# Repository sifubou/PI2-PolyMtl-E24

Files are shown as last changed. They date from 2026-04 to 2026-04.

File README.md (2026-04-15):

# Le Dalmachien 🐕‍🦺

Prototype de chien robot autonome conçu dans le cadre du cours **MEC2105 · Projet Intégrateur II** (Polytechnique Montréal, Hiver 2026).

**Équipe 24 · Groupe 02**
Adam Bouaddi · Rose Mélançon · Liliane Leclerc-Ko · Miguel Azoury · Ryan Kangue Essomé Simeu · William Lalonde

## Mission
Parcourir une piste de compétition, déposer un jouet poulet dans la zone cible, s'immobiliser dans deux cercles rouges successifs avec battement de queue et clignotement LED, puis exécuter une rotation complète dans le cercle BONUS.

## Matériel
- Microcontrôleur : Arduino Uno
- Moteurs : 2 × DC TT bleu, 110 tr/min (haut couple)
- Servomoteurs : 3 × MG90S (2 tête, 1 queue)
- Gyroscope : MPU6050 (asservissement des rotations)
- Alimentation : 2 × piles Li-ion 18650 (3500 mAh)
- LED : anneau NeoPixel 20 × WS2812

## Bibliothèques Arduino requises
- `Servo.h` (standard)
- `Adafruit_NeoPixel`
- `Wire.h` (standard, pour I²C du MPU6050)

## Brochage
| Fonction | Pin Arduino |
|---|---|
| Moteur IN1, IN2, IN3, IN4 | 2, 3, 4, 7 |
| Servo queue | 12 |
| Servo tête gauche / droite | 9 / 10 |
| LED NeoPixel | 6 |
| MPU6050 (I²C SDA/SCL) | A4 / A5 |

## Calibration
- `VITESSE_MS = 7000` ms/m (à calibrer sur la piste réelle)
- `DEG_PAR_SEC = 112` °/s (régulation gyroscopique)

## Fichiers
- `arduino/V3.ino` — programme du parcours complet (parcours obligatoire + BONUS)

## Licence
MIT

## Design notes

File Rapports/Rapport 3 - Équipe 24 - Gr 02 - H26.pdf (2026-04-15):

M E C 2 1 0 5 – P R O J E T I N T É G R A T E U R I I

Gr : 02

# RAPPORT 3

# Le Dalmachien

Projet intégrateur 2 : Robot chien

Présenté à

Vincent Di Pietro, ing.

Par l'équipe no 24

Rose Melançon • Adam Bouaddi • Liliane Leclerc-Ko

Miguel Azoury • Ryan Kangue Essome Simeu • William Lalonde

Hiver 2026 • Montréal

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
## TABLE DES MATIÈRES

### 01 Présentation de la solution

### 02 Essais du prototype

### 03 Analyse de la solution

### 04 Dessins techniques

### 05 Nomenclature

### 06 Conclusion

MEC2105 – Projet Intégrateur II – Équipe 24

A
A

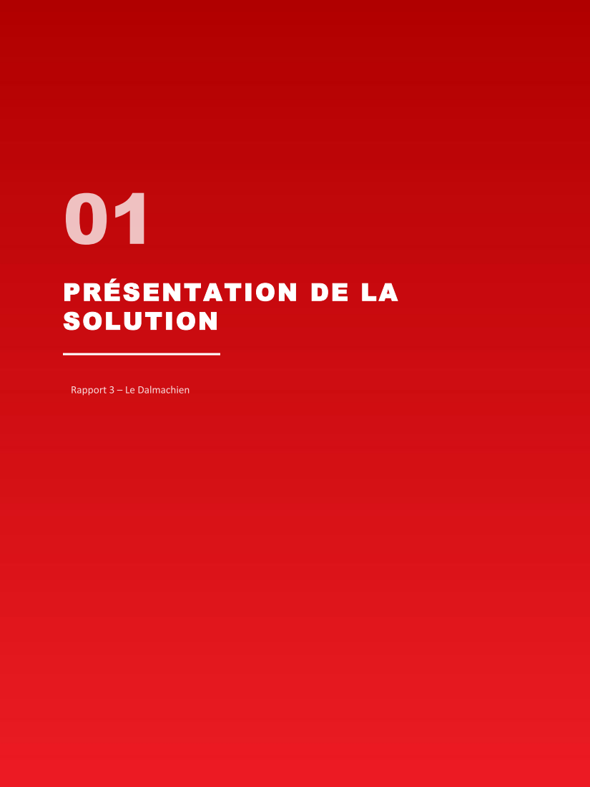
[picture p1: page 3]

PRÉSENTATION DE LA
SOLUTION

1

2

3

4

5

6

1 . P R É S E N T A T I O N

## Description de la solution

1.1 – Vue d'ensemble du Dalmachien

MEC2105 – Projet Intégrateur II – Équipe 24 | Section 1

Le Dalmachien (figure 1) est un robot chien qui répond parfaitement aux besoins des étudiants de l'école régionale du Vent-Nouveau. Il est composé de trois sous-systèmes : La queue, la tête et le châssis.

Figure 1 – Le Dalmachien

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
1 . P R É S E N T A T I O N

## Sous-système du chassis

1.1 – Description de la solution

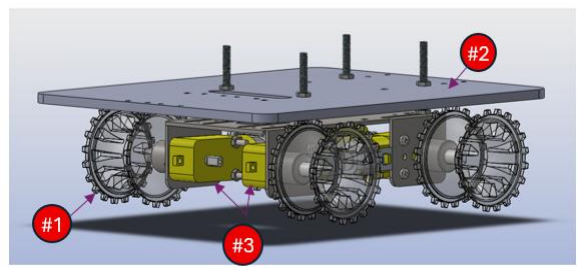
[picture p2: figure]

Figure 2 – Le sous-système du châssis

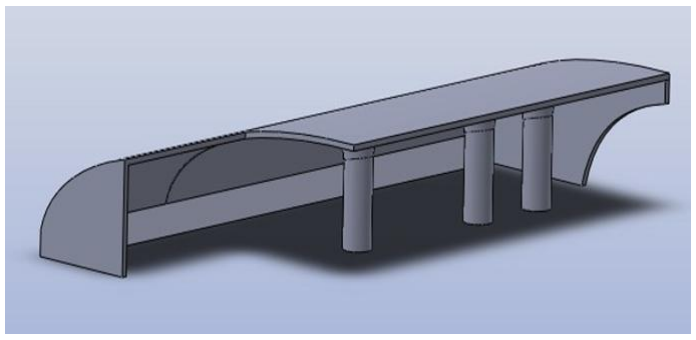
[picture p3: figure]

Figure 3 – Coquille du sous-système du châssis

### 1.1.1 Sous-système du châssis

Le premier sous-système est celui du châssis (voir figure 2). Sa pièce maîtresse est un châssis acheté, muni de chenilles (#1) et de deux moteurs DC (#3). Le sous-système comporte aussi un étage en acrylique (#2) qui permet de fixer toutes les pièces du système de contrôle : les servomoteurs, les moteurs, le pont H, les piles, le circuit électrique, etc. Il est aussi muni de la coquille en PLA (voir figure 3) qui permet de recouvrir les pièces techniques pour améliorer l'aspect esthétique du robot chien.

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
1 . P R É S E N T A T I O N

## Sous-systèmes tête et queue

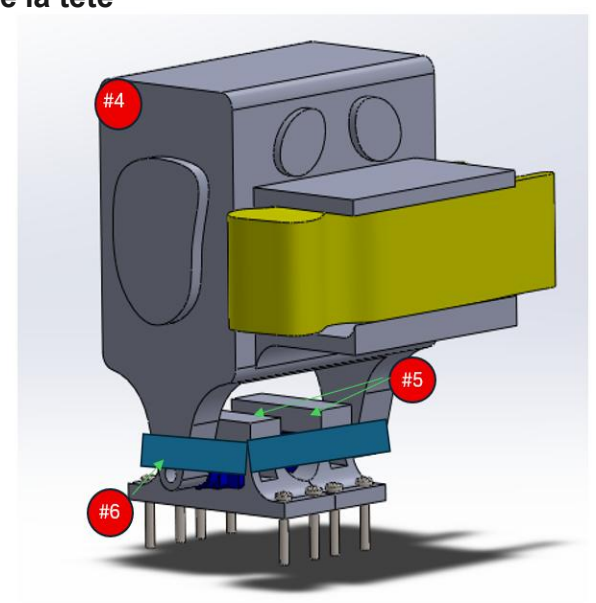
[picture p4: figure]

Figure 4 – La tête

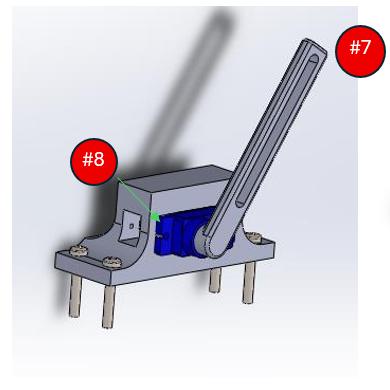
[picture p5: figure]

Figure 5 – La queue

Le deuxième sous-système est celui de la tête (voir figure 4). Il est composé de la tête en PLA (#4) qui sert à transporter le jouet poulet (illustré en jaune) et est recouvert d’une bande LED (#6) dans le bas du cou. La mâchoire est fixe et seulement le cou est contrôlé par deux servos moteurs (#5). La rotation permet de bien déposer le jouet poulet.

### 1.1.2 Sous-système de la tête

### 1.1.2 Sous-système de la queue

Le dernier sous-système est celui de la queue (voir figure 5). La composante principale est la queue imprimée en PLA (#7) directement fixée sur un servo moteur (#8). Elle est fixée sur l’étage du sous-système du châssis à l’arrière du robot.

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
1 . P R É S E N T A T I O N

## Axes d’améliorations

La solution initiale comportait une coquille en un morceau. Pour faciliter le montage et le démontage, le Dalmachien utilise maintenant 2 coquilles symétriques (figure 3) qui s'insèrent sur les tiges de l'étage (#2). La taille du chien a été réduite et la tête allégée.
De plus, la mâchoire est directement imprimée sur la tête du robot (figure 4), sans moteur, fonctionnelle uniquement par rotation du cou.

### 1.1.4 Amélioration du concept

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
1 . P R É S E N T A T I O N

## Fonctionnement de la solution

1.2 – Mécanismes principaux
Dans cette section, on décrit le fonctionnement des mécanismes principaux qui permettent au Dalmachien de remplir ses fonctions principales : battre de la queue, allumer un voyant lumineux, se déplacer, s'orienter et manipuler un jouet poulet (voir Annexe A).

### 1.2.1 Battre de la queue

Le mécanisme du sous-système de la queue (voir figure 5) est l’un des systèmes les plus simples du robot. Il fait appel à une queue imprimée en 3D, accouplée sur l’axe d’un servo-moteur à l’aide d’une vis. Grâce au microcontrôleur Arduino UNO, on vient commander le servo-moteur, pour moduler l’amplitude de battement et la vitesse des cycles de battement de la queue.

### 1.2.2 Allumer un voyant lumineux

Pour la fonction principale du robot-chien traitant du voyant clignotant, le Dalmachien utilise une bande LED (voir figure 4 #6) collée sur la partie inférieure de la tête du chien. Avec le microcontrôleur, on vient contrôler la couleur, l’intervalle de clignotement, ainsi que l’intensité lumineuse de la bande LED.

### 1.2.3 Se déplacer

Pour bouger, le Dalmachien utilise un système de roues-chenilles faisant partie du sous-système du châssis (voir figure 2), propulsé par deux roues motrices motorisées par deux moteurs DC. Les deux autres roues, indépendantes et libres sur leurs axes, permettent aux chenilles de maintenir leur forme et leur tension. Elles sont accouplées aux boîtiers de deux moteurs DC, dont nous avons enlevé le moteur et le réducteur de vitesse, pour que leurs arbres deviennent libres et sans résistance. Pour contrôler son mouvement, les deux moteurs sont branchés à un contrôleur à moteur en pont H L293D (voir figure 6 pour le branchement, encadré en vert), qui en conjonction avec le microcontrôleur Arduino, permet de moduler le sens de rotation et la puissance de sortie des deux moteurs. Pour avancer, on commande aux deux moteurs de tourner vers l’avant, ce qui ensuite transmet le mouvement aux chenilles, qui elles transmettent la force au sol pour venir déplacer le robot. Pour reculer, le robot applique la même séquence d’action, sauf pour un sens inverse de rotation des moteurs.

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
1 . P R É S E N T A T I O N

## Fonctionnement de la solution

1.2 – Mécanismes principaux

### 1.2.5 Déposer le jouet poulet

Afin de transporter le jouet poulet de façon fiable, le Dalmachien fait recours à une mâchoire inférieure et supérieure espacées d'une longueur précise, ainsi qu'à une nervure au bout de la mâchoire inférieure (voir figure 4), de façon à ce que le jouet soit sécure dans la bouche du chien lors du déplacement. Ensuite, pour déposer le jouet poulet, le Dalmachien penche sa tête d'environ 90 degrés vers l'avant jusqu'à ce que le poids du jouet suffise pour qu'il s'échappe de la bouche et tombe juste en dessous. Ce qui permet le mouvement de la tête du chien, ce sont deux servomoteurs ancrés à deux points de pivots à la base du cou (voir figure 4 #5). Ceux-ci sont aussi commandés par le microcontrôleur Arduino, qui vient moduler leurs angles de rotation.

Pour changer de direction, le robot fait tourner chacune de ses chaînes dans le sens opposé à l'autre, à la même vitesse de rotation. Le chien pivote ainsi sur son axe azimutal sur 360 degrés, lui permettant de s'orienter dans n'importe quelle direction. Il peut soit tourner vers la gauche ou vers la droite, dépendamment si la chenille de gauche ou celle de droite tourne vers l'avant. Pour effectuer tout ceci, le robot utilise les mêmes composantes que pour se déplacer vers l'avant ou l'arrière, soit le microcontrôleur Arduino, le contrôleur de moteur L293D et les 2 moteurs DC.

### 1.2.4 S'orienter

Figure 6 - Circuit électrique du Dalmachien

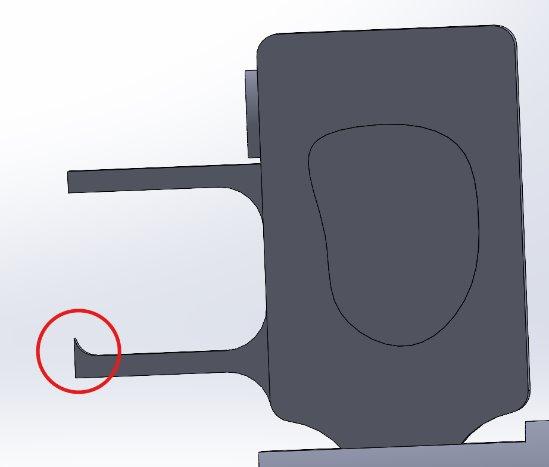
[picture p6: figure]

Figure 7 - Vue de côté de la tête

A
A

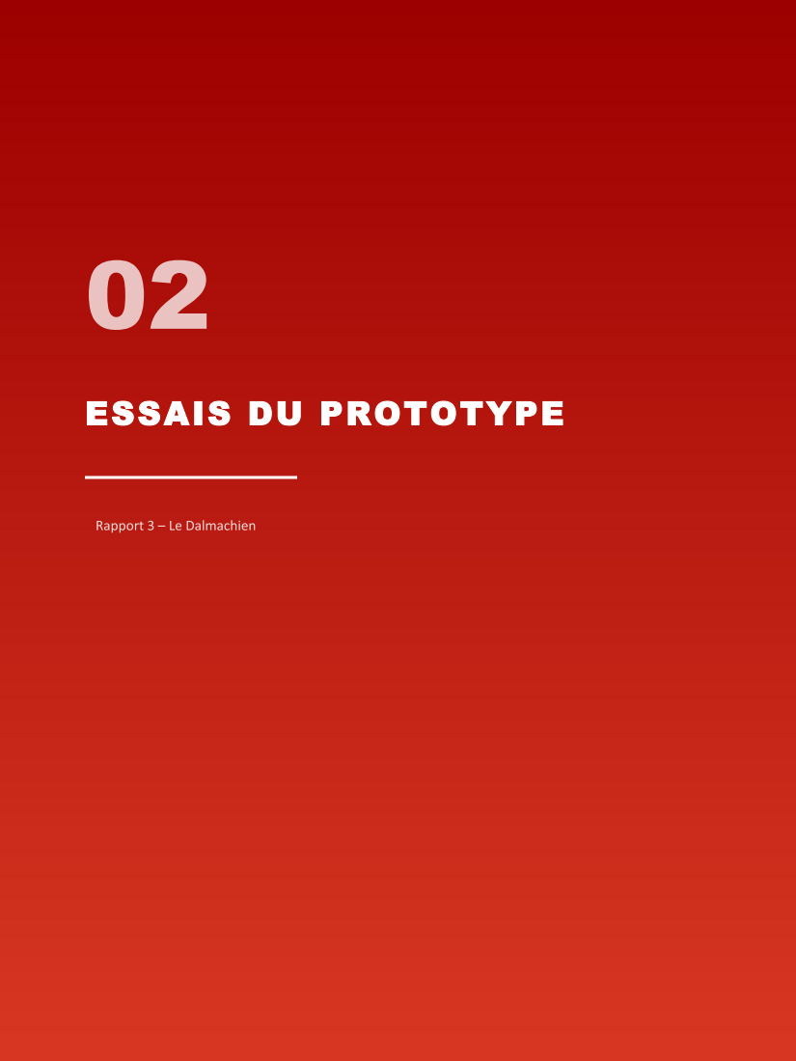
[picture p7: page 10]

ESSAIS DU PROTOTYPE

1

2

3

4

5

6

2 . E S S A I S

## Méthodologie générale

Protocole d'essai
L'ensemble des essais présentés dans ce rapport a été réalisé les 27 et 28 mars 2026. Chaque essai a été intégralement filmé afin de permettre une analyse rigoureuse a posteriori (voir Annexe I). Tous les essais sont numérotés, datés et rattachés aux fonctions principales (FP) du cahier des charges ainsi qu'aux paramètres de l'équation de performance.

Les vidéos ont été analysées à l'aide d'un logiciel de montage permettant un avancement image par image. La caméra utilisée opère à une fréquence de 60 Hz, ce qui correspond à une résolution temporelle d'environ 16,7 ms par image. La résolution spatiale de la caméra (inférieure à 4K) engendre également une incertitude estimée à ±5° sur les mesures angulaires.

En complément, une analyse de la piste audio a été effectuée afin de détecter les pics de bruit associés à l'activation des moteurs DC et des servomoteurs. Cette technique a permis d'améliorer la précision sur la détermination des instants de début et de fin de mouvement, en corroborant l'information visuelle.

SOURCES D'IMPRÉCISION IDENTIFIÉES

Taux de rafraîchissement limité à 60 Hz (±16,7 ms), résolution vidéo non 4K (±5° sur les angles), et maintien manuel du socle lors de certains essais (section 4).

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
2 . E S S A I S

## Essai n°1 : Locomotion et immobilisation

FP-1.0 et FP-1.1 – 27 mars 2026 – Paramètres D et temps
Cet essai porte sur les fonctions FP-1.0 (Se déplacer) et FP-1.1 (S'immobiliser). Ces fonctions sont directement liées aux paramètres D (distance parcourue) et temps (temps chronométré) de l'équation de performance (voir Annexe D).

Le prototype a été positionné sur une surface plane. Une distance de référence de 1 mètre a été marquée au sol. Le robot a été démarré par le bouton-poussoir et le chronométrage a été effectué par analyse vidéo image par image, corroboré par l'analyse audio de l'activation des moteurs. Le temps a été mesuré entre le premier déplacement détecté et l'immobilisation complète du prototype. Cinq (5) essais consécutifs ont été réalisés dans les mêmes conditions.

Essai | Temps (s) | Vitesse (m/s)
1 | 3,47 | 0,288
2 | 3,29 | 0,304
3 | 3,28 | 0,305
4 | 3,41 | 0,293
5 | 3,36 | 0,298
Moyenne | 3,36 | 0,298

Tableau 1 – Résultats des essais de locomotion (distance : 1 m)

L'écart-type calculé sur le temps est de 0,080 s. Le meilleur temps enregistré est de 3,28 s (essai n°3).

A NA L Y S E

La répétabilité des mesures est satisfaisante, avec un écart-type de 0,080 s sur cinq essais. La vitesse moyenne de 0,298 m/s permet de parcourir la distance maximale du parcours (Dmax = 178 cm) en environ 6 secondes, ce qui est largement inférieur à la limite de 120 secondes imposée. Le prototype s'immobilise de manière complète et sans rebond à chaque essai, validant ainsi la fonction FP-
1.1. Le système de propulsion par chenilles offre une traction stable et rectiligne sur la surface de la piste.

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
2 . E S S A I S

## Essai n°2 : Battement de queue

FP-5.0, FP-5.1, FP-5.2 – 27 mars 2026 – Param. S2, P3 = 100 pts

Un total de 36 mesures a été réalisé. Quatre angles cibles ont été programmés dans le servomoteur MG90S (90°, 120°, 150° et 180°) pour trois durées de cycle visées (1 s, 1,5 s et 2 s), chaque combinaison étant répétée trois fois. L'angle de battement a été mesuré par analyse vidéo image par image. La durée du cycle a été déterminée par combinaison de l'analyse vidéo et de l'analyse de la bande son, en repérant le pic acoustique correspondant à l'activation du servomoteur (voir Annexe E).

Angle | Durée | t1 (s) | t2 (s) | t3 (s) | Obs. moy. | Précision
90° | 1 s | 1,05 | 1,05 | 1,01 | 82° | 91,1 %
90° | 1,5 s | 1,53 | 1,53 | 1,53 | 85° | 94,4 %
90° | 2 s | 2,03 | 2,06 | 2,06 | 85° | 94,4 %
120° | 1 s | 1,01 | 1,11 | 1,08 | 105° | 87,5 %
120° | 1,5 s | 1,63 | 1,56 | 1,56 | 110° | 91,7 %
120° | 2 s | 2,05 | 2,08 | 2,10 | 110° | 91,7 %
150° | 1 s | 1,06 | 1,10 | 1,06 | 135° | 90,0 %
150° | 1,5 s | 1,65 | 1,63 | 1,56 | 140° | 93,3 %
150° | 2 s | 2,05 | 2,00 | 2,11 | 140° | 93,3 %
180° | 1 s | 0,96 | 0,96 | 0,96 | 158° | 87,8 %
180° | 1,5 s | 1,65 | 1,65 | 1,60 | 170° | 94,4 %
180° | 2 s | 2,00 | 2,00 | 2,00 | 170° | 94,4 %

Tableau 2 – Résultats des 36 mesures de battement de queue

A NA L Y S E
Les résultats montrent que le servomoteur MG90S produit un battement de queue reproductible pour l'ensemble des configurations testées. On observe un écart systématique d'environ 10° entre la consigne et l'angle observé pour la consigne de 90°, attribuable aux limites mécaniques du montage (jeu dans l'axe, inertie de la pièce de queue). Cet écart est problématique car il est impératif de dépasser les 90° par rapport à la verticale lors de la compétition. La précision angulaire s'améliore avec l'augmentation de l'angle cible, atteignant 93,3 % pour 150° et 94,4 % pour 180°.

Pour la compétition, la configuration retenue sera un angle cible de 150° ou 180° avec une durée de cycle de 1,5 seconde. À 150°/1,5 s, l'angle observé moyen est de 140° ; à 180°/1,5 s, il est de 170°. Les résultats de ces deux configurations sont proches et compte tenu de l'imprécision des mesures (±5°), ils peuvent être considérés comme similaires. Les deux dépassent largement le minimum requis de 90° et offrent une marge de sécurité confortable. La durée de cycle mesurée (environ 1,6 s en moyenne) satisfait le minimum de 1 seconde exigé. Les exigences des spécifications FP-5.0, FP-5.1 et FP-5.2 sont validées.

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
2 . E S S A I S

## Essai n°3 : Inclinaison de la tête

FP-4.0 et FP-4.3 – 28 mars 2026 – Param. O

Cet essai porte sur les fonctions FP-4.0 (Manipuler la charge utile) et FP-4.3 (Déposer un objet dans une zone prédéterminée). L'ouverture de la gueule à 90° (position horizontale) permet la libération du jouet poulet par gravité. Ce mécanisme influence directement le paramètre O de l'équation de performance (voir Annexe F).

La tête du chien robot, fabriquée par impression 3D, est actionnée par deux servomoteurs MG90S. Deux angles cibles ont été testés : 70° (position intermédiaire) et 90° (position horizontale nécessaire au dépôt). Cinq tests ont été réalisés pour chaque angle cible, soit un total de 10 mesures. L'angle a été mesuré par analyse vidéo image par image.

Il est important de noter deux limitations de cet essai. Premièrement, le socle du prototype était tenu manuellement durant les tests, ce qui introduit une source d'imprécision. Deuxièmement, un jouet de test a été utilisé en remplacement du jouet poulet officiel fourni lors de la compétition. La géométrie et la masse de ce jouet de test diffèrent légèrement du modèle réel.

Test | Obs. 70° | Obs. 90°
Test 1 | 70° | 80°
Test 2 | 70° | 85°
Test 3 | 70° | 88°
Test 4 | 70° | 90°
Test 5 | 70° | 90°
Moyenne | 70,0° | 86,6°

Tableau 3 – Résultats des essais d'inclinaison de la tête

A N A L Y S E

L'angle de 70° est atteint avec une précision de 100 % sur les cinq essais, ce qui confirme la fiabilité du mécanisme à cette position. Pour l'angle de 90°, on observe un écart moyen de −3,4° (moyenne de 86,6°). Cependant, une amélioration progressive est notée au fil des tests : les deux premiers tests donnent 80° et 85°, tandis que les deux derniers atteignent exactement 90°. Ce comportement suggère un léger rodage mécanique des servomoteurs. L'ouverture à 90° est suffisante pour que le jouet soit libéré par gravité, ce qui a été confirmé visuellement lors des essais avec le jouet de test. Une validation complémentaire avec le jouet poulet officiel sera nécessaire avant la compétition. Les conditions de maintien manuel du socle sont à considérer dans l'interprétation de ces résultats.

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
2 . E S S A I S

## Essai n°4 : Visibilité du voyant LED

FP-3.0, FP-3.1, FP-3.2 – 28 mars 2026 – Param. S1, P3 = 100 pts

Sept couleurs ont été évaluées sur le ruban LED installé au niveau du collier : blanc, jaune, vert, rouge, cyan, bleu et magenta. Trois critères ont été évalués, chacun noté sur 5 : le confort visuel (caractère apaisant de la couleur, particulièrement pertinent pour le public cible souffrant de TSA), la visibilité de face, et la visibilité depuis l'angle de l'enfant (position assise à environ 1,40 m de hauteur). L'évaluation a été conduite dans des conditions d'éclairage intérieur normales. Un score moyen a été calculé pour chaque couleur (voir Annexe G).

Couleur | Rang | Confort (/5) | Face (/5) | Angle (/5) | Score moy.
Vert | 1 | 5,0 | 2,0 | 3,5 | 3,50
Jaune | 2 | 4,5 | 2,0 | 3,5 | 3,33
Cyan | 3 | 3,5 | 2,0 | 3,5 | 3,00
Blanc | 4 | 4,0 | 2,0 | 2,5 | 2,83
Rouge | 5 | 3,0 | 2,0 | 2,5 | 2,50
Bleu | 6 | 2,5 | 2,0 | 2,0 | 2,17
Magenta | 7 | 2,0 | 2,0 | 2,0 | 2,00

Tableau 4 – Évaluation comparative des couleurs LED

A NA L Y SE

La couleur verte se classe en première position avec un score global de 3,50/5. Son confort visuel est évalué à 5/5 : la lumière est perçue comme douce et non agressive, ce qui est un critère prioritaire compte tenu du profil des élèves de l'École (TSA). Le jaune (3,33/5) et le cyan (3,00/5) suivent en deuxième et troisième positions.

Il est à noter que la visibilité de face est uniformément basse (2,0/5 pour toutes les couleurs). Cette limitation provient de la géométrie de la tête imprimée en 3D, dont la structure masque partiellement le ruban LED lorsque l'observateur se situe directement devant le robot. Ce point pourrait être amélioré lors d'une itération future du design. La couleur verte est retenue pour la compétition. Le clignotement à intervalle de 1 seconde (FP-3.1) a également été validé visuellement lors de ces essais.

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
2 . E S S A I S

## Essai n°5: rotation complète

FP-2.0 (Rotation) et justification des modifications (2.2)

Cet essai porte sur la fonction FP-2.0 (Tourner sur lui-même). Il est lié au paramètre BONUS de l'équation de performance, où P3 = 100 points si le chien a tourné sur lui-même selon les spécifications (270° minimum). Onze durées de commande ont été testées, de 2 500 ms à 3 500 ms par incréments de 100 ms, avec une cible de rotation de 360°. L'angle a été mesuré par analyse vidéo image par image. Les chenilles ont parfois glissé sur la surface d'essai, introduisant une source d'imprécision supplémentaire (voir Annexe H).

Durée (ms) | Angle Obs. (°) | Écart vs 360° (°) | Précision (%) | Δ Angle vs Moy. | Statut
2500 | 260 | -100 | 72,2 % | -61,4 | Sous-rotation
2600 | 275 | -85 | 76,4 % | -46,4 | Sous-rotation
2700 | 275 | -85 | 76,4 % | -46,4 | Sous-rotation
2800 | 285 | -75 | 79,2 % | -36,4 | Sous-rotation
2900 | 295 | -65 | 81,9 % | -26,4 | Sous-rotation
3000 | 315 | -45 | 87,5 % | -6,4 | Sous-rotation
3100 | 340 | -20 | 94,4 % | +18,6 | Sous-rotation
3200 | 360 | 0 | 100,0 % | +38,6 | Parfait
3300 | 370 | +10 | 97,2 % | +48,6 | Sur-rotation
3400 | 375 | +15 | 95,8 % | +53,6 | Sur-rotation
3500 | 385 | +25 | 93,1 % | +63,6 | Sur-rotation
MOYENNE | 321,4 | -38,6 | 86,7 % | — | —

Tableau 3 – Résultats des 11 mesures de rotation (FP-2.0)

A NA L Y S E

La durée optimale est de 3 200 ms, produisant un angle observé de 360° (précision de 100 %). Pour des durées inférieures, le robot effectue une sous-rotation (260° à 340°). Pour des durées supérieures, une sur-rotation est observée (370° à 385°). L'angle moyen sur les 11 tests est de 321,4° avec un écart moyen de −38,6° par rapport à la cible et une précision moyenne de 86,7 %.

La configuration retenue pour la compétition est une durée de 3 200 ms. À cette valeur, le robot effectue une rotation complète de 360°, dépassant largement le minimum requis de 270°. Un renforcement de l'adhérence des chenilles est envisagé pour la compétition afin d'éliminer le phénomène de glissement. La fonction FP-2.0 est validée.

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
2 . E S S A I S

## Pièces modifiées

### 7.3 Queue (pièce fabriquée)

Fabrication : Pièce imprimée en 3D, actionnée par un seul servomoteur MG90S. Justification : Un seul servomoteur est suffisant pour produire un battement latéral conforme aux spécifications (amplitude minimale de 45°, durée de cycle minimale de 1 s), tel que démontré par les 36 mesures présentées à la section 3.

### 2.2 Pièces modifiées et justification (2.2)

### 7.1 Châssis à chenilles (pièce achetée, modifiée)

Pièce d'origine : Kit châssis-chenille commercial équipé de quatre (4) moteurs DC. Modification apportée : Réduction à deux (2) moteurs. Les pièces mécaniques devenues superflues (supports moteurs, engrenages) ont été retirées. L'arbre de sortie de chaque côté a été conservé afin de maintenir la fixation des quatre (4) roues nécessaires à l'entraînement des chenilles. Justification : Cette modification répond à trois objectifs. Premièrement, la réduction de la consommation énergétique : l'utilisation de deux moteurs au lieu de quatre diminue le courant total demandé aux piles 18650, ce qui favorise l'utilisation d'une seule pile (paramètre E = 2 dans l'équation de performance). Deuxièmement, l'allègement du prototype : le retrait de deux moteurs et de leurs supports mécaniques contribue à respecter la masse limite de 1,5 kg. Troisièmement, la simplification du câblage électrique et du contrôle par le microcontrôleur.

### 7.2 Tête du chien robot (pièce fabriquée)

Fabrication : Impression 3D (PLA). La tête intègre la gueule articulée (dépôt par mouvement vers le bas), les logements pour les deux servomoteurs MG90S et le passage du ruban LED au niveau du collier. Justification du choix : L'impression 3D permet d'obtenir une géométrie personnalisée qui évoque l'apparence d'un chien (critère de design), tout en intégrant précisément les logements fonctionnels pour les servomoteurs et le ruban LED. Le servomoteur MG90S a été retenu pour son couple suffisant (2,2 kg·cm) et sa faible masse (13,4 g par unité).

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
2 . E S S A I S

## Synthèse de conformité

Tableau récapitulatif

Fonction | Spécification | Conforme ? | Param.
FP-1.0 Déplacement | Piste 122 × 183 cm | Oui | D, temps
FP-1.1 Immobilisation | Arrêt total | Oui | S1, S2 (P1A)
FP-2.0 Rotation | ≥ 270° | Oui | BONUS (P3)
FP-3.0 Voyant LED | Visible, ≥ 300 mcd | Oui | S1 (P3)
FP-3.1 Intervalle | 1 seconde | Oui | S1 (P3)
FP-5.0 Queue | ≥ 45°, cycle ≥ 1 s | Oui | S2 (P3)
FP-4.0 Jouet poulet | Dépôt en zone bleue | Oui* | O

Tableau 5 – * Validé avec un jouet de test. À revalider avec le jouet poulet officiel.

Les essais réalisés démontrent que le prototype de l'équipe 24 satisfait l'ensemble des spécifications du cahier des charges pour les fonctions principales testées (voir Annexes A et B). La méthodologie mise en place, combinant l'analyse vidéo image par image et l'analyse de la bande son, a permis d'obtenir des mesures quantitatives fiables tout en identifiant les sources d'imprécision associées. Les modifications apportées au châssis acheté sont justifiées par des critères de performance énergétique, de masse et de simplicité. Les pièces fabriquées (tête, queue) répondent aux exigences fonctionnelles et esthétiques du projet. L'essai de rotation (FP-2.0) confirme que le robot effectue une rotation complète de 360° à 3 200 ms, validant l'admissibilité au parcours bonus.

A
A

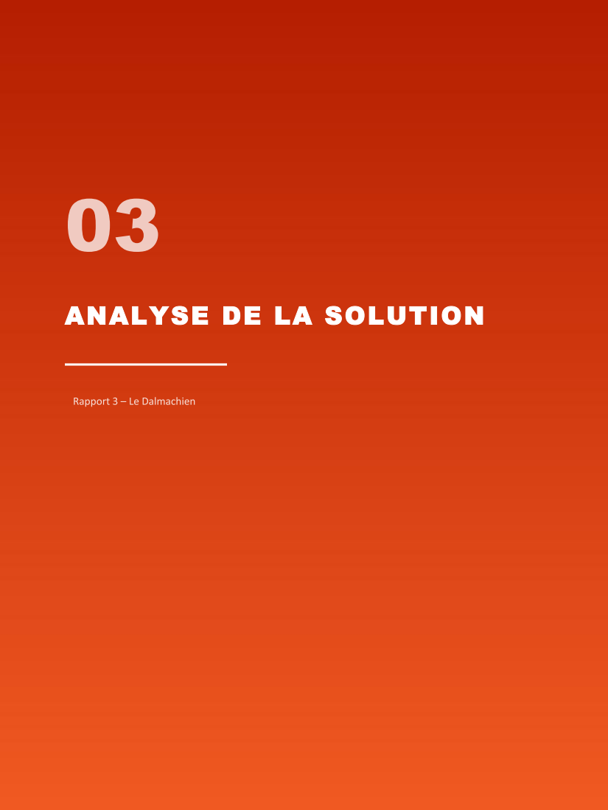
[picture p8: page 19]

ANALYSE DE LA SOLUTION

1

2

3

4

5

6

3 . A N A L Y S E

## Calculs de résistance des matériaux

3.1 – Pièce critique : plaque du châssis ACH-001

Pour les calculs de résistance des matériaux, la pièce critique du prototype est la plaque du châssis des chenilles (ACH-001). C'est une plaque en aluminium robuste qui tient tout le poids du chien à l'exception des chenilles. Il y a 8 vis (indiquées sur l'image suivante par les ×) qui tiennent tout le poids se situant en haut du châssis.

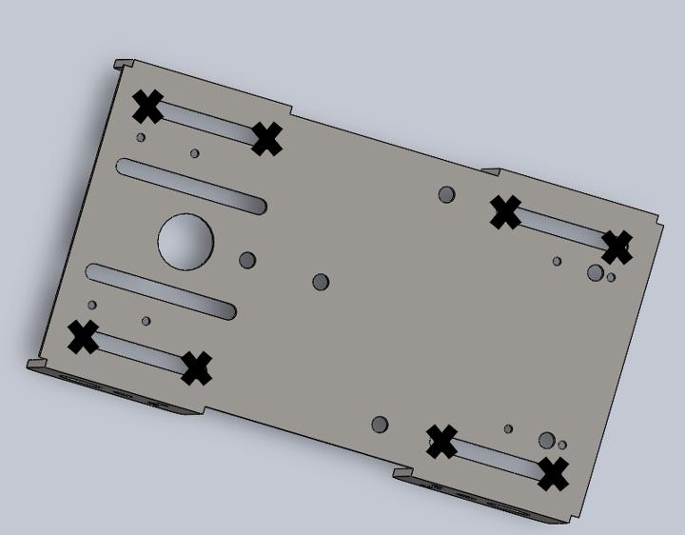
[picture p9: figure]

Figure 1 – Points critiques du châssis (ACH-001)

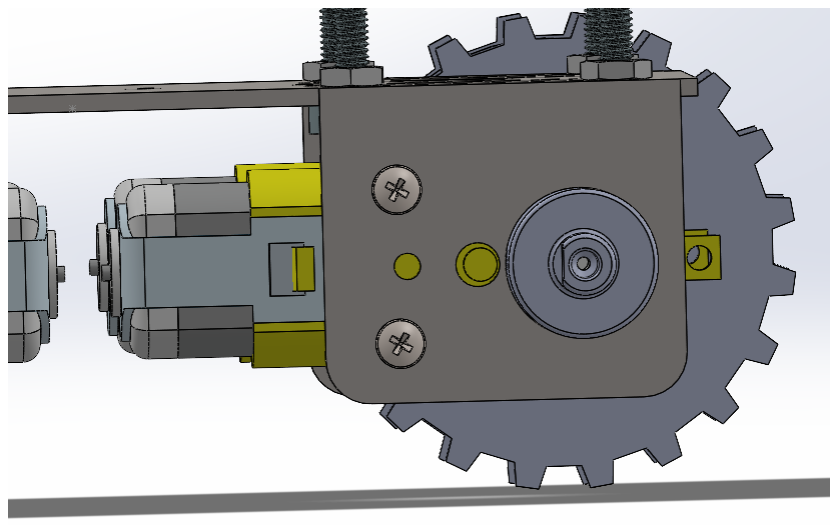
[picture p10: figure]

Propriété | Valeur | Source
Matériau | Alliage d'aluminium 6061 | –
Limite d'élasticité | 275 MPa | Matweb.com
Module d'Young | 69 GPa | Matweb.com

Figure 2 – Vue d'ensemble du châssis avec moteurs et roues

A
A

## Graphiques des forces appliquées

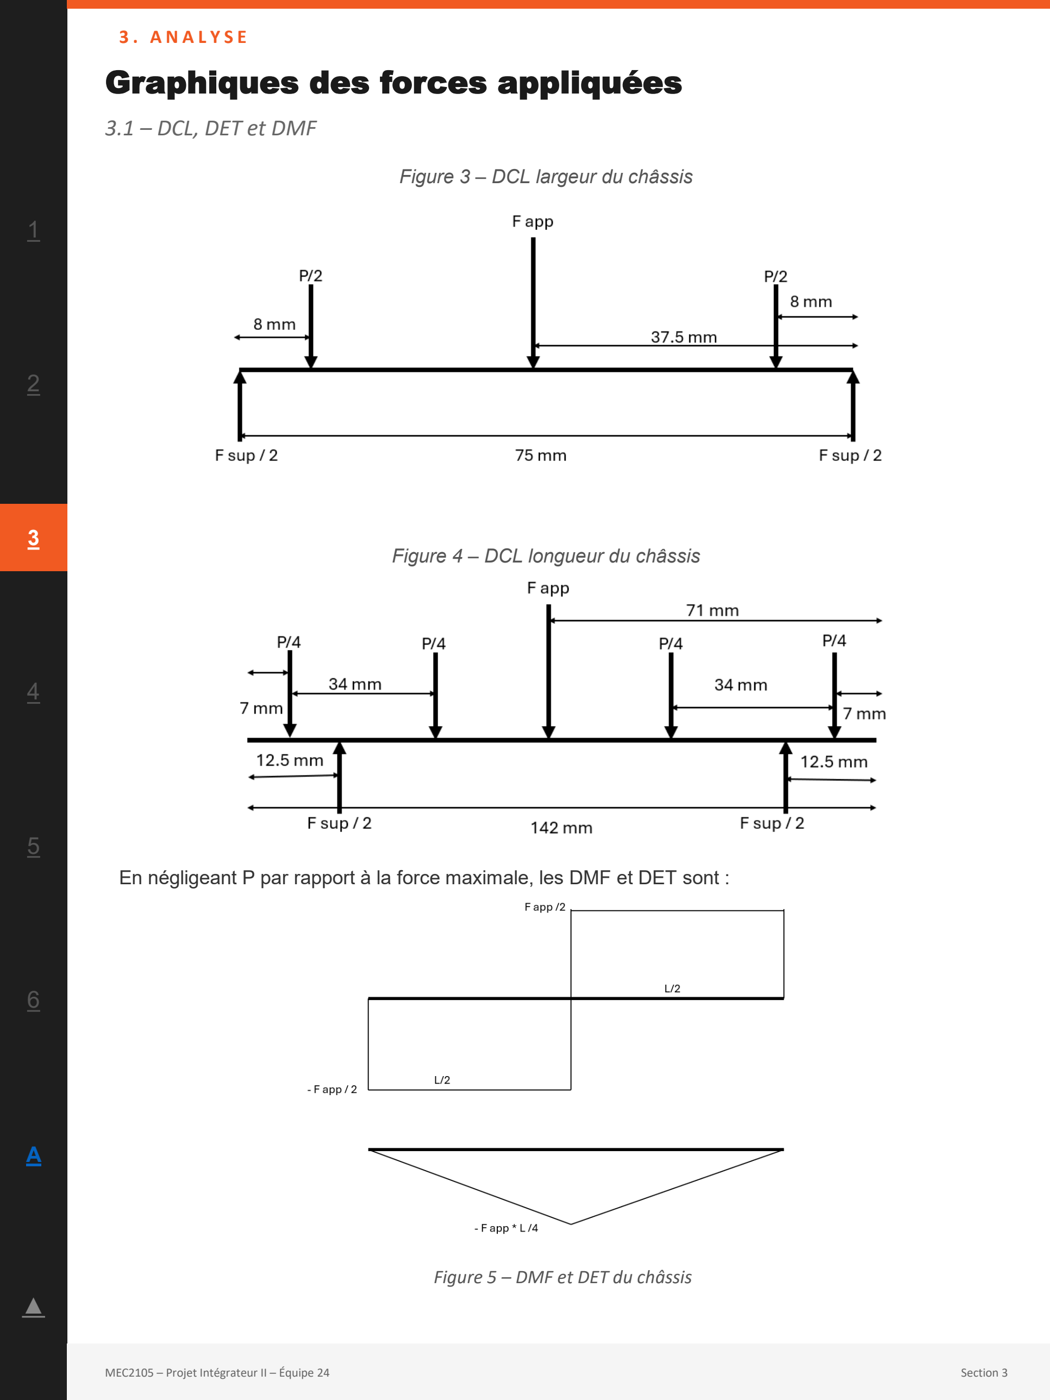
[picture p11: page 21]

1

2

3

4

5

6

3 . A N A L Y S E

3.1 – DCL, DET et DMF

Figure 3 – DCL largeur du châssis

Figure 4 – DCL longueur du châssis

En négligeant P par rapport à la force maximale, les DMF et DET sont :

Figure 5 – DMF et DET du châssis

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
3 . A N A L Y S E

## Calcul de la force maximale

3.1 – Force maximale et concentration de contrainte

L est la longueur (142 mm pour la longueur, 75 mm pour la largeur). Le moment maximal est Fapp×L/4 au centre.
La contrainte maximale en flexion :

σ =

My
I
Où M est le moment, y la distance au centre, I le moment d'inertie :

I =

b ⋅ ℎ

3
12
En isolant Fmax :

Fmax =

σ ⋅ 4 ⋅ I
L ⋅ y
Application numérique :

Ilong =

75 ⋅ 2

3
12 = 50 mm ⁴

Fnom,long =

275 ⋅ 4 ⋅ 50
142 ⋅ 1

= 387 N

Ilargeur = 142 × 2³ / 12 = 94,67 mm⁴

Fnom,long = (275 × 4 × 50) / (142 × 1) = 387 N Fnom,larg = (275 × 4 × 94,67) / (75 × 1) = 1 388 N

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
3 . A N A L Y S E

## Concentration de contrainte

3.1 – Force maximale et concentration de contrainte

### Calcul de concentration de contrainte

La force de 387 N représente la contrainte maximale si la plaque était rectangulaire sans trous. Dans le cas du châssis, il y a plusieurs trous, donc il y aurait une concentration de contraintes à certains endroits qui mettent plus à risque le châssis. Pour tenir compte de la concentration de contrainte, il faut utiliser le facteur de concentration de contrainte (Kt). La force maximale qui peut être appliquée devient donc Fmax / Kt. Dans le cas du châssis, le Kt peut être à 3,1 à certains endroits.

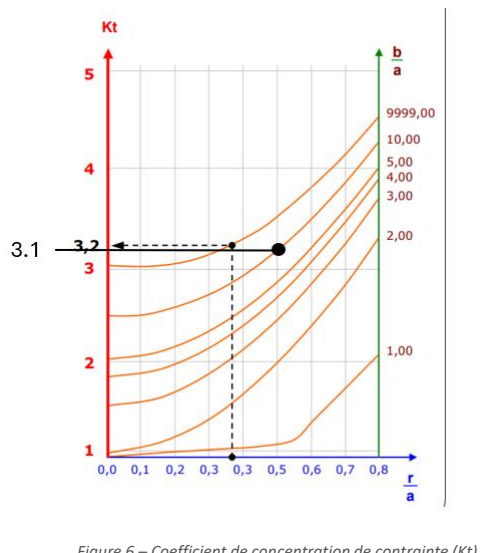
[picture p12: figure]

Figure 6 – Coefficient de concentration de contrainte (Kt)

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
3 . A N A L Y S E

## Concentration de contrainte et flèche réelle

3.1 – Kt, flèche sous force réelle

Pour le coefficient de concentration de contrainte dans la plaque, les trous critiques sont ceux qui sont sur la longueur. Dans ces cas, le b/a est d'environ 10 et le r/a est environ 0,5 donc le facteur de concentration de contrainte est de 3,1. Pour une valeur plus précise, il faudrait faire une analyse par éléments finis sur toute la plaque pour trouver les points critiques et évaluer le Kt à ces endroits.

La force maximale pouvant être appliquée est donc de 387 N / 3,1 = 124 N.

### Calcul de la flèche pour la force réelle appliquée

Pour la largeur du châssis, la déflexion maximale est δ = Fa/(24EI) × (3L² − 4a²)

La force réelle appliquée par le poids du chien-robot est m × g où m est la masse supportée par le châssis et g est l'accélération gravitationnelle. Dans ces calculs, m = 0,621 kg et g = 9,81 m/s². La force réelle est donc 6,09 N.

δ_largeur = (F/2 × a) / (24 × E × I) × (3L² − 4a²)

E (le module de Young) est 69 GPa et comme illustré dans le DCL, L = 75 mm et a = 8 mm.
δlargeur = ((6,09/2 × 8))/ (24 × 69 × 10^3 × 94,67) × (3 × 75^2 − 4 × 8^2 ) δlargeur = 0,00258 mm

Pour la longueur, si on approxime les forces appliquées aux 4 points au centre de la plaque :
δ = FL³/(48EI) = 6,09 × 142³ / (48 × 69×10³ × 50) = 0,105 mm

L'hypothèse de mettre les forces au centre à la place de faire le calcul avec la distribution surestime la valeur de la flèche, donc la valeur réelle sera plus petite que 0,105 mm avec la force réelle. C'est une valeur très petite qui montre que la plaque ne va pas subir de déformation significative avec la force.
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
3 . A N A L Y S E

## Concentration de contrainte et flèche réelle

3.1 – Kt, flèche sous force réelle

Calcul de la flèche pour la force maximale

Si on applique la force maximale possible avant l'atteinte de la limite d'élasticité, on peut négliger la force du poids du chien. Dans ce cas, la flèche maximale est δ = FL³/(48EI) :

δlongueur = 124 ×

142³
48 × 69 × 10³ × 50 = 2,14 mm

δlargeur = 124 × 75³ / (48 × 69 × 10³ × 94,67) = 0,167 mm

La flèche pour la force maximale est donc d'environ 2 mm, ce qui est beaucoup considérant la longueur de 142 mm, mais dans le cas du chien robot, la force maximale de 124 N (≈ 13 kg sur Terre) ne devrait pas être atteinte, donc la flèche ne devrait pas être problématique.

3.1 – Vis, facteur de sécurité et tableaux récapitulatifs

Calcul de cisaillement dans une vis

Sur la plaque, il y a 8 vis qui supportent la force appliquée et le poids qui se situe au-dessus de la plaque. Il y a donc une contrainte de cisaillement qui doit être prise en compte. Avec l'hypothèse que chaque vis supporte 1/8 de la force à supporter, la contrainte de cisaillement est τ = F/A où F est la force que la vis supporte et A, l'aire de la surface de la vis. F est donc égale à Fmax/8 et A est π·d²/4. La résistance à la traction de la vis est 70 000 psi (Lily Bearing, n.d.) donc 582,6 MPa. La contrainte de cisaillement est égale à 0,6 × σmax ce qui donne donc τmax = 349,6 MPa. En raison du filetage, le diamètre minimal est 2,5 mm puisque les filets sont de 0,5 mm. Puisque A = π × 2,5² / 4 = 4,91 mm², la force maximale que la vis supporte est Fmax = τmax × A = 349,6 MPa × 4,91 mm² = 1 716 N par vis.

Pour assurer qu'il n'y aurait pas de bris dans la vis, il faut considérer un facteur de sécurité. Pour la sécurité de la vis et du chien-robot, le facteur de sécurité considéré sera 2,5 ce qui fait que Fnom = 1 716/2,5 = 686,4 N par vis ou 5 491,2 N au total.

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
3 . A N A L Y S E

## Cisaillement et synthèse des calculs

3.1 – Vis, facteur de sécurité et tableaux récapitulatifs
Calcul de cisaillement dans une vis

Sur la plaque, il y a 8 vis qui supportent la force appliquée et le poids qui se situe au-dessus de la plaque. Il y a donc une contrainte de cisaillement qui doit être prise en compte. Avec l'hypothèse que chaque vis supporte 1/8 de la force à supporter, la contrainte de cisaillement est τ = F/A où F est la force que la vis supporte et A, l'aire de la surface de la vis. F est donc égale à Fmax/8 et A est π·d²/4. La résistance à la traction de la vis est 70 000 psi (Lily Bearing, n.d.) donc 582,6 MPa. La contrainte de cisaillement est égale à 0,6 × σmax ce qui donne donc τmax = 349,6 MPa. En raison du filetage, le diamètre minimal est 2,5 mm puisque les filets sont de 0,5 mm. Puisque A = π × 2,5² / 4 = 4,91 mm², la force maximale que la vis supporte est Fmax = τmax × A = 349,6 MPa × 4,91 mm² = 1 716 N par vis.

Pour assurer qu'il n'y aurait pas de bris dans la vis, il faut considérer un facteur de sécurité. Pour la sécurité de la vis et du chien-robot, le facteur de sécurité considéré sera 2,5 ce qui fait que Fnom = 1 716/2,5 = 686,4 N par vis ou 5 491,2 N au total.

Tableaux synthèse

Cas | Flèche
Force réelle – Largeur | 0,00258 mm
Force réelle – Longueur | 0,105 mm
Force max. – Largeur | 0,167 mm
Force max. – Longueur | 2,14 mm

Tableau – Flèches des différents cas

Force maximale admissible | Valeur
Sur la largeur | (1388/3,1) = 447,7 N
Sur la longueur | 124 N
Sur les vis (FS = 2,5) | 5 491,2 N

Tableau – Forces maximales applicables. La force limite est de 124 N.

Références : Matweb (n.d.), Aluminium 6061. Lily-Bearing (n.d.), JCAJFABIF. École Nationale des Ingénieurs de Brest (2021), ÉTUDE DES CONSTRUCTIONS (p.1-7).

Déclaration IA : L'IA générative a été utilisée uniquement pour des suggestions ou corrections mineures (orthographe, grammaire) et l'amélioration d'éléments visuels.

A
A

## Tolérancement géométrique

1

2

3

4

5

6

3 . A N A L Y S E

3.2 – Support de servomoteur (CUS-005)
Pour le support de servomoteur qui permet de fixer les différents servomoteurs à l'étage (CUS-005) du chien-robot. Les différents supports sont imprimés en PLA en 3D.

Figure 7 – Support de servomoteur (CUS-005)

Figure 8 – Dessin dimensionnel

Figure 9 – Chaîne de cotes A A

1

2

3

4

5

6

3 . A N A L Y S E

## Tolérancement géométrique

3.2 – Support de servomoteur (CUS-005)

A₁ est la longueur du servo-moteur et A₂ est la longueur du trou du support.
J₁ min = 0,1 mm puisque le servo-moteur doit pouvoir rentrer dans le trou du support.
A₂ = L₂ ± 0,4 mm puisque c'est fait en impression 3D avec une buse de 0,4 mm. A₁ = 22,6 ± 0,2 mm. L'incertitude est justifiée par le fait que les servomoteurs sont faits de manière industrielle avec un moule.

J₁ min + A₁ max = A₂ min
A₂ min = L₂ − 0,4 mm = 0,1 mm + 22,8 mm = 22,9 mm L₂ = 23,3 mm
J₁ max = A₂ max − A₁ min = 23,3 + 0,4 − 22,4 = 1,3 mm

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
3 . A N A L Y S E

## Revue de design – Page 1

3.3 – Informations générales et documents intrants

Revue de design n°1, 27 mars 2026. Sujet : Conception du prototype. Phase du projet : Phase 3 (conception) (voir Annexe C).

PARTICIPANTS

Nom | Rôle
Rose Melançon | Secrétaire de la revue
Adam Bouaddi | Gestionnaire d'équipe
Liliane Leclerc-Ko | Secrétaire d'équipe
Miguel Azoury | Conception CAD
Ryan Kangue Essome Simeu | Conception CAD
William Lalonde | Conception

Secrétaire de la revue (rédacteur) : Rose Melançon. Destinataire : Vincent Di Pietro, ing.

DOCUMENTS INTRANTS

Document | Type | Commentaires
Cahier de charges fonctionnel | Intrant | Comporte les fonctions principales évaluées
Dessin technique de la tête | Intrant | Dimensions et géométrie de la gueule du chien
Code Arduino | Intrant | Contrôle des servomoteurs pour tous les systèmes
Cahier d'instructions du client | Externe | Demandes et contraintes imposées

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
3 . A N A L Y S E

## Revue de design – Page 2

3.3 – Vérification des fonctions principales

No. | Ré v. | Fonction | K | Vér . | O K | Commentaires / explications
FP-1.0 | 2 | Se déplacer | 5 | X | X | Les chenilles installées sur le châssis du robot lui permettent d'avancer facilement et rapidement selon le code Arduino (document intrant #3).
FP-1.1 | 2 | S'immobiliser | 5 | X | X | Le code Arduino (document intrant #3) qui contrôle les moteurs du châssis, permet au robot de s'immobiliser parfaitement.
FP-2.0 | 2 | Tourner sur lui-même | 5 | X | X | Le code Arduino (document intrant #3) qui contrôle les moteurs du châssis, permet au robot de tourner sur lui-même.
FP-3.0 | 2 | Allumer un voyant | 4 | X | X | La bande LED contrôlée par le code Arduino (document intrant #3) permet d'allumer le voyant lumineux.
FP-3.1 | 2 | S'allumer en intervalle | 4 | X | X | La bande LED contrôlée par le code Arduino (document intrant #3) permet d'allumer le voyant lumineux sur une intervalle de temps contrôlée.
FP-3.2 | 2 | Être visible à distance | 3 | X | X | La bande LED assure la visibilité à distance.
FP-4.0 | 2 | Manipuler la charge | 3 | X | X | La gueule du chien robot (document intrant #2) permet de réaliser la tâche concernant le jouet poulet.
FP-4.1 | 2 | Transporter un objet | 3 | X | X | La position horizontale de la gueule lors des déplacements, permet au robot de transporter le jouet sur une distance prédéfinie (document intrant #2).
FP-4.2 | 2 | Maintenir l'objet | 3 | X | X | Le bas de la gueule est modélisé afin d'empêcher le jouet de basculer vers l'avant (document intrant #2).
FP-4.3 | 2 | Déposer en zone | 3 | X | X | Le code Arduino (document intrant #3) qui contrôle le robot, fait baisser la gueule complètement horizontalement afin que le jouet soit déposé dans la zone.
FP-5.0 | 2 | Battre de la queue | 4 | X | X | Le code Arduino (document intrant #3) permet à la queue fixée au servomoteur de battre pendant 3 répétitions.
FP-5.1 | 2 | Contrôler la cadence | 4 | X | X | Le code Arduino (document intrant #3) indique à la queue de respecter un temps programmé entre chaque battement.
FP-5.2 | 2 | Maintenir l'amplitude | 3 | X | X | Le code Arduino (document intrant #3) indique à la queue de respecter l'amplitude de 45 degrés selon la position verticale.
FP-6.0 | 2 | Démarrer via bouton | 4 | X | X | L'interrupteur permet le démarrage et l'arrêt instantané du robot.

Sur papier, le Dalmachien remplit toutes les fonctions principales parfaitement. Selon les tests, le prototype réussit aussi à effectuer toutes les fonctions principales. La prochaine revue servira à évaluer les contraintes appliquées sur ses fonctions et à améliorer l'esthétique du robot pour la conception finale. Nous n’avons pas de Nouvelles taches à attribuer,

A
A

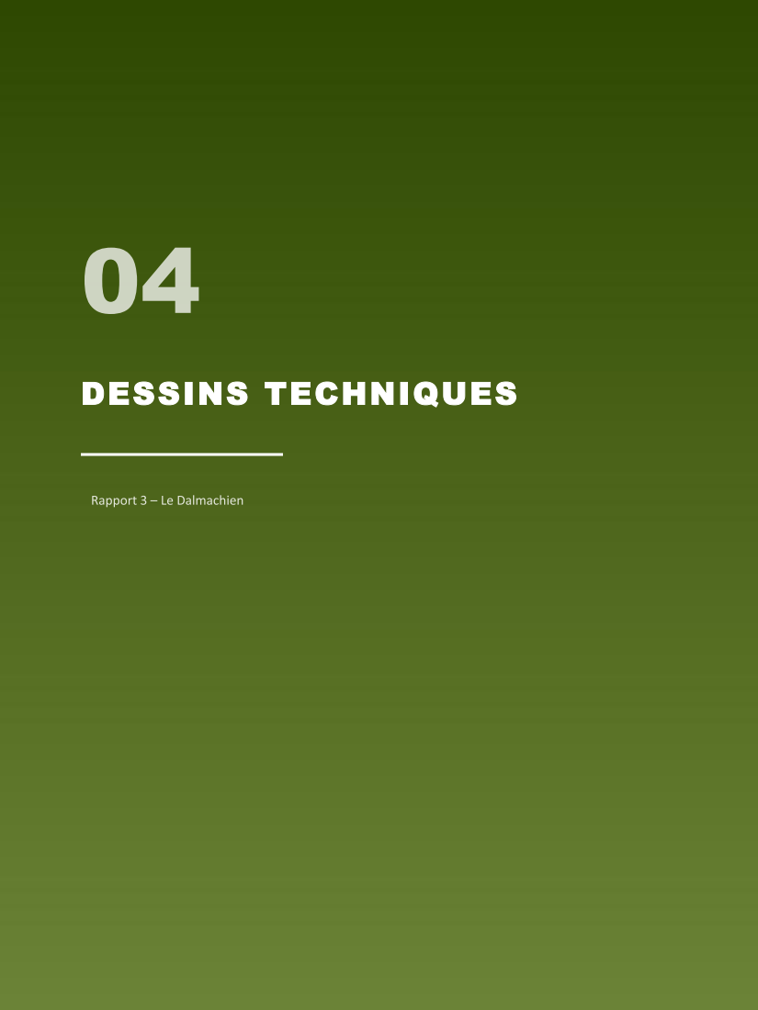
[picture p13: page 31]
DESSINS TECHNIQUES

1

2

3

4

5

6

4 . D E S S I N S

## Assemblage final (1/3)

4.1 – Dessins d'assemblage

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
4 . D E S S I N S

## Assemblage final (2/3)

4.1 – Dessins d'assemblage

A
A

1

2

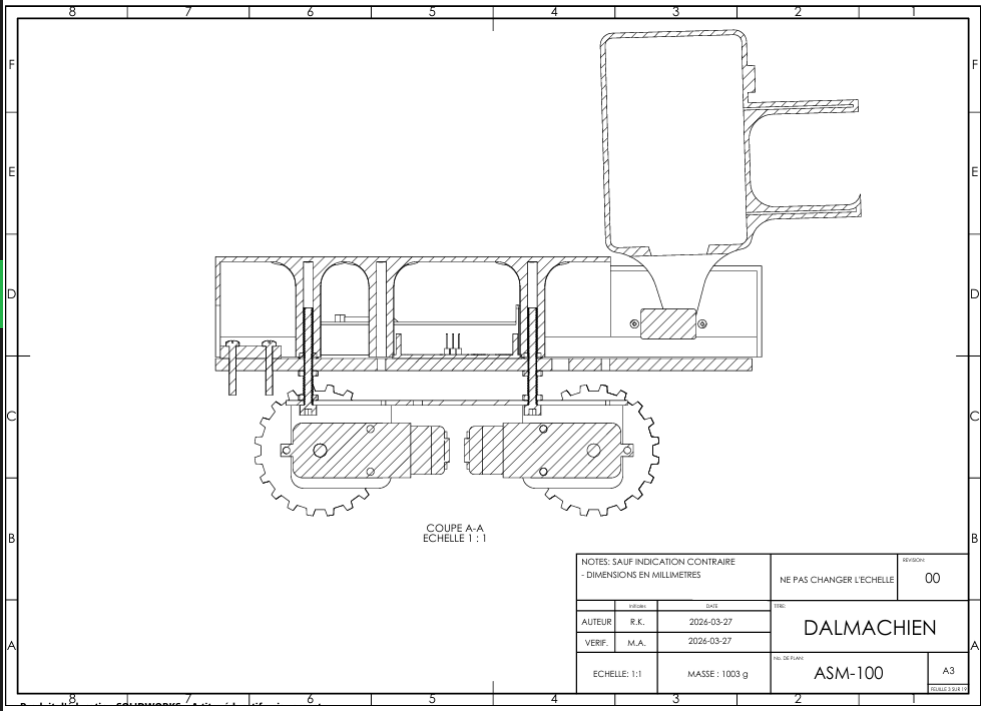
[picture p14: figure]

3

4

5

6

4 . D E S S I N S

## Assemblage final (3/3)

4.1 – Dessins d'assemblage

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
4 . D E S S I N S

## Assemblage Servo (1/2)

4.1 – Dessins d'assemblage

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
4 . D E S S I N S

## Assemblage Servo (2/2)

4.1 – Dessins d'assemblage

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
4 . D E S S I N S

## Assemblage Tête (1/2)

4.1 – Dessins d'assemblage

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
4 . D E S S I N S

## Assemblage Tête (2/2)

4.1 – Dessins d'assemblage

A
A

1

2

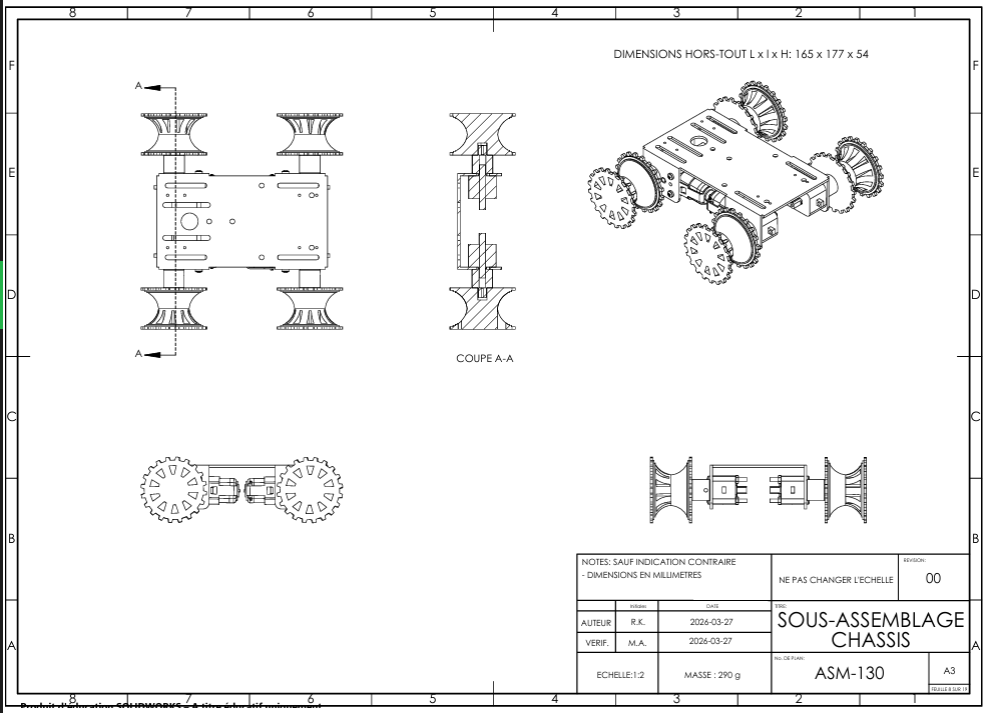
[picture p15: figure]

3

4

5

6

4 . D E S S I N S

## Assemblage Châssis (1/2)

4.1 – Dessins d'assemblage

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
4 . D E S S I N S

## Assemblage Châssis (2/2)

4.1 – Dessins d'assemblage

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
4 . D E S S I N S

## Assemblage Queue (1/2)

4.1 – Dessins d'assemblage

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
4 . D E S S I N S

## Assemblage Queue (2/2)

4.2 – Dessins de détails

A
A

1

2

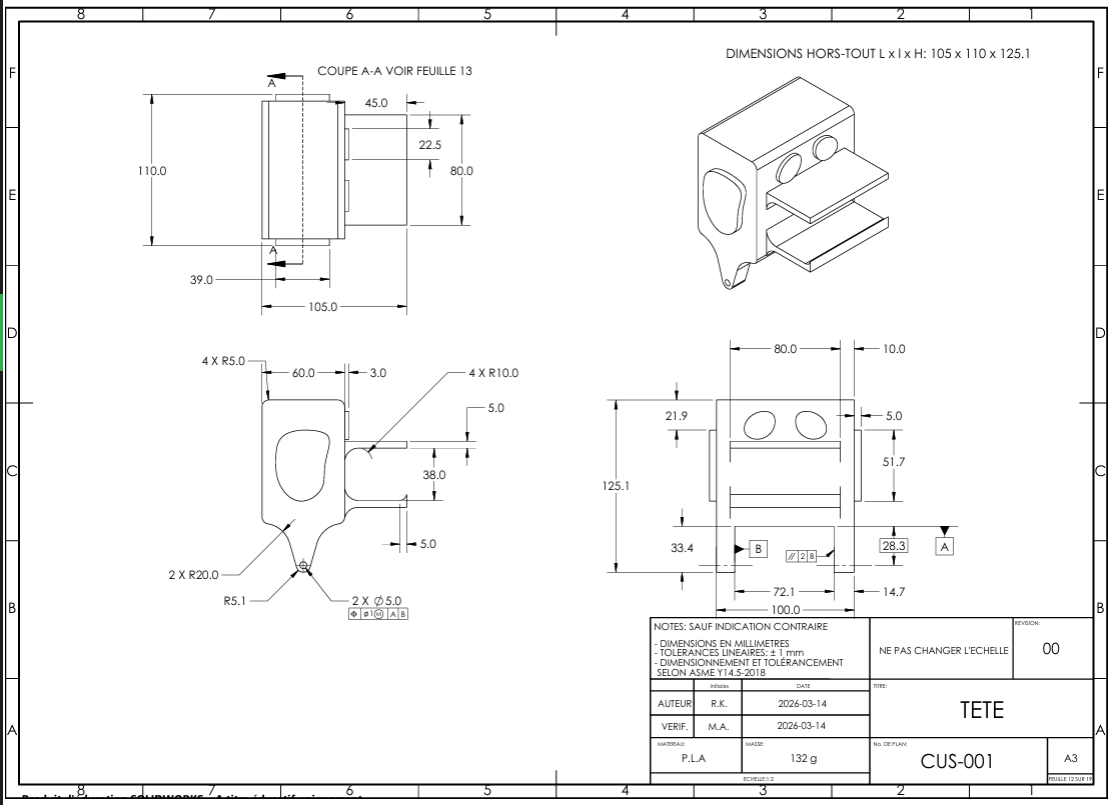
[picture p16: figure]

3

4

5

6

4 . D E S S I N S

## Tête (1/2)

4.2 – Dessins de détails

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
4 . D E S S I N S

## Tête (2/2)

4.2 – Dessins de détails

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
4 . D E S S I N S

## Étage

4.2 – Dessins de détails

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
4 . D E S S I N S

## Corps (1/2)

4.2 – Dessins de détails

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
4 . D E S S I N S

## Corps (2/2)

4.2 – Dessins de détails

A
A

1

2

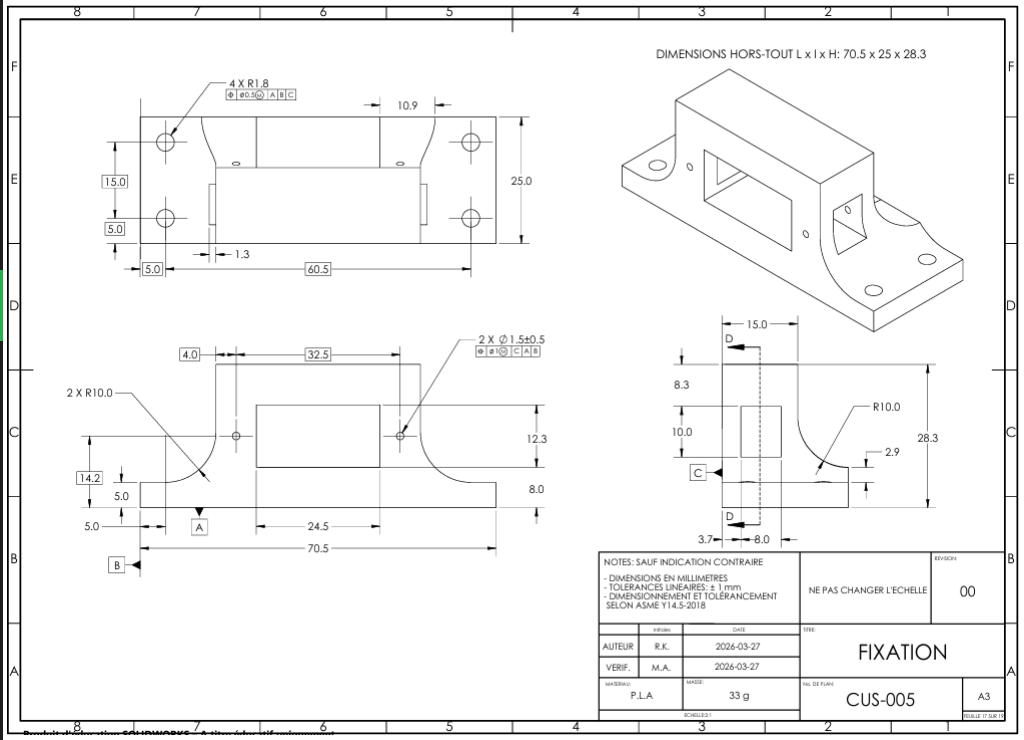
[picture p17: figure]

3

4

5

6

4 . D E S S I N S

## Fixation (1/2)

4.2 – Dessins de détails

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
4 . D E S S I N S

## Fixation (2/2)

4.2 – Dessins de détails

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
4 . D E S S I N S

## Queue

4.2 – Dessins de détails

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
4 . D E S S I N S

## Synthèse des pièces fabriquées

4.3 – Matériaux, procédés et justification

Pièce | Matériau | Procédé de fabrication | Justification
CUS-002 Étage | Acrylique 5 mm | Découpe laser | Offre une meilleure précision de positionnement des trous que l'impression 3D
CUS-005 Fixation | PLA | Sablage | Augmente la rugosité de surface, ce qui améliore l'adhérence et la résistance au glissement
CUS-006 Queue | PLA | Perçage | Agrandit le trou à la base pour y monter une vis de Ø5 mm

A
A

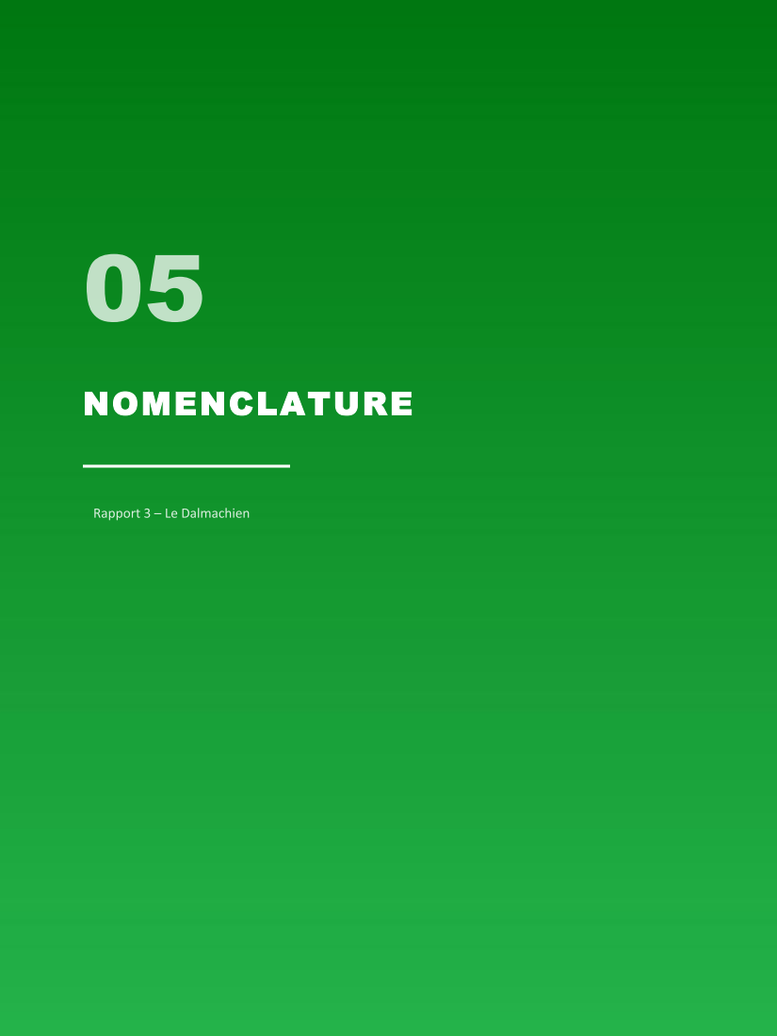
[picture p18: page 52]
NOMENCLATURE

1

2

3

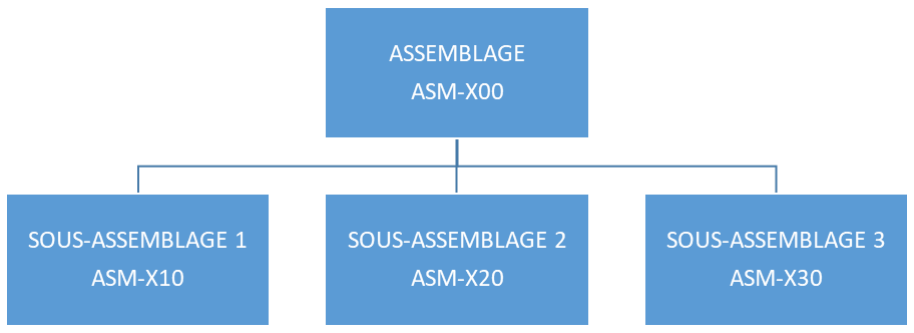
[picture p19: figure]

4

5

6

5 . N O M E N C L A T U R E

## Classification des pièces

5.1 – Système de nomenclature
Afin d'identifier les différentes pièces et sous-assemblages, il a été décidé de séparer les pièces en trois catégories : les pièces standards, les pièces achetées et les pièces fabriquées. De plus, au niveau de la classification des sous-assemblages, il a été choisi d'utiliser une classification alphanumérique, où l'assemblage général prend une certaine centaine, et les dizaines qui suivent décrivent les sous-assemblages qui le constituent (voir Annexe J).

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
5 . N O M E N C L A T U R E

## Arbre de nomenclature

5.2 – Nomenclature détaillée des pièces

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
5 . N O M E N C L A T U R E

## Nomenclature des dessins

5.3 – Nomenclature détaillée des dessins

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
5 . N O M E N C L A T U R E

## Liste des pièces

5.4 – BOM complet

Id | Description | Mat. | Fourniss eur | Qt é | Masse (g) | Coût ($)
ACH-001 | Base châssis | Acier | ABRA | 1 | 180,0 | 45,00
ACH-002 | Moteur TT | – | ABRA | 4 | 80,0 | –
ACH-003 | Pignon | Acier | ABRA | 4 | 8,0 | –
ACH-004 | Rouage | Plast. | ABRA | 4 | 16,0 | –
ACH-005 | Arduino | – | ABRA | 1 | 65,0 | 30,00
ACH-006 | Motor-driver | – | ABRA | 1 | 25,0 | 20,00
ACH-007 | Batteries | – | ABRA | 2 | 100,0 | 30,00
ACH-008 | Servo | – | ABRA | 3 | 30,0 | 30,00
ACH-008 | Chenille | Plast. | ABRA | 2 | 6,0 | –
CUS-001 | Tête | PLA | Custom | 1 | 132,0 | 17,16
CUS-002 | Étage | Acryl. | Custom | 1 | 75,0 | 9,75
CUS-003 | Corps | PLA | Custom | 1 | 65,4 | 8,50
CUS-004 | Corps-miroir | PLA | Custom | 1 | 65,5 | 8,52
CUS-005 | Fixation | PLA | Custom | 3 | 100,5 | 13,07
CUS-006 | Queue | PLA | Custom | 1 | 17,0 | 2,21
STAND-001 | M4×50 Bolt | Acier | McMaste r | 4 | 52,8 | 3,00
STAND-002 | M4 Hex Nut | Acier | McMaste r | 12 | 9,6 | 4,20
STAND-003 | M3 Hex Nut | Acier | McMaste r | 20 | 8,0 | 8,00
STAND-004 | M3×30 Bolt | Acier | McMaste r | 8 | 16,0 | 1,60
STAND-006 | M3×20 Bolt | Acier | McMaste r | 12 | 16,8 | 3,00
TOTAL | | | | | 1 068,6 | 234,00

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
5 . N O M E N C L A T U R E

## BOM des sous-assemblages

5.5 – Détail par sous-assemblage

ASM-100 (Assemblage général) – 1 002,55 g / 211,40 $

Id | Description | Qté | Masse (g) | Coût ($)
ASM-120 | S-ASM Tête | 1 | 219,0 | 41,87
ASM-130 | S-ASM Châssis | 1 | 290,0 | 45,00
ASM-140 | S-ASM Queue | 1 | 60,5 | 14,57
CUS-002 | Étage | 1 | 75,0 | 9,75
CUS-003 | Corps-miroir | 1 | 65,4 | 8,50
CUS-004 | Corps | 1 | 65,5 | 8,52
STAND-001 | M4×50 Bolt | 4 | 52,8 | 3,00
STAND-002 | M4 Hex Nut | 12 | 9,6 | 4,20
STAND-003 | M3 Hex Nut | 20 | 8,0 | 8,00
STAND-006 | M3×20 Bolt | 12 | 16,8 | 3,00
ACH-005 | Arduino | 1 | 65,0 | 30,00
ACH-006 | Motor-driver | 1 | 25,0 | 20,00
ACH-007 | Batteries | 1 | 50,0 | 15,00

ASM-110 (Servo) – 43,50 g / 12,36 $
Id Id | Qté Qté | Masse Masse | Coût Coût
CUS-005 | 1 | 33,5 | 4,36
ACH-008 | 1 | 10,0 | 8,00

ASM-120 (Tête) – 219,00 g / 41,87 $

ASM-110 | 2 | 87,0 | 24,71
CUS-001 | 1 | 132,0 | 17,16
ASM-130 (Châssis) – 290,00 g / 45,00 $ | ASM-140 (Queue) – 60,50 g / 14,57 $

A
A

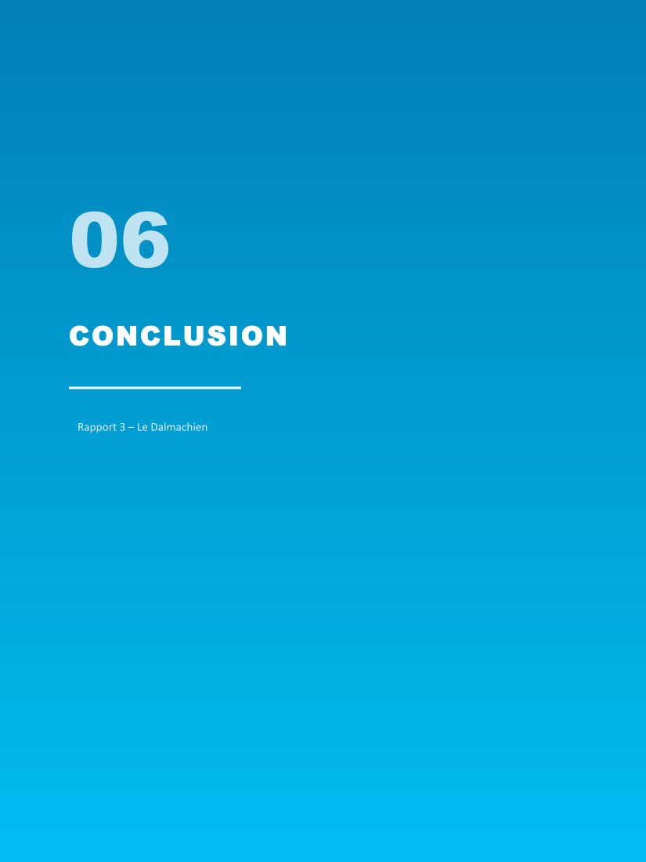
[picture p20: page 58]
CONCLUSION

1

2

3

4

5

6

6 . C O N C L U S I O N

## Conclusion

Bilan du projet Le Dalmachien

Ce troisième rapport avait pour objectif de présenter l’étude complète du produit final, nommé « Le Dalmachien », ainsi que de rendre compte des avancements réalisés au niveau du prototypage du robot-chien.

Le prototype actuel permet de remplir l’ensemble des fonctions définies dans le cahier des charges établi au préalable, grâce aux différents sous-systèmes intégrés au robot : le châssis, la tête et la queue. Les essais effectués sur chaque sous-système, puis sur le prototype dans sa globalité, ont démontré que le produit est désormais en phase finale de développement et bientôt prêt à être livré.

Sur le plan de la résistance mécanique, l’analyse a révélé que la pièce critique ACH-001, correspondant à la base du châssis, est en mesure de supporter une charge de 124 N avant d’atteindre la zone plastique de déformation, ce qui confirme la robustesse structurelle de la conception.

Enfin, après compilation de l’ensemble des pièces et composants, il a été déterminé que le robot-chien présente une masse totale de 1 070 g pour un coût de fabrication estimé à environ 234 $.

Il convient toutefois de souligner que, bien que le projet soit en phase de finalisation, une marge d’amélioration subsiste, notamment en ce qui concerne l’optimisation des sous-systèmes existants ainsi que le perfectionnement de l’ergonomie générale du produit.

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
A N N E X E S

## Annexe A – Fonctions principales (CdCF)

Cahier des charges fonctionnelles

MEC2105 – Projet Intégrateur II – Équipe 24 | Annexe A
No. | RÉV. | FONCTION | K | CRITÈRE | NIVEAU | FLEXIBILITÉ | COMMENTAIRES
FP | | Fonctions principales
FP-1.0 | 2 | Se déplacer | 5 | Bouger sur à travers la piste sans franchir la zone limite | Dimensions de la piste | Aucune | Évaluation de la facilité avec laquelle le robot peut se déplacer
FP-1.1 | 2 | S'immobiliser | 5 | Arriver à une vitesse 0 | Vitesse de freinage | Aucune | Évaluation de la décceleration
FP-2.0 | 2 | Tourner sur lui-même | 5 | Tourner dans les cercles rouge de la piste | Cercle de rayon 25 cm | +0 cm / minimum ouvert | Facilité qu'a le robot à tourner sur lui-même dans un cercle de rayon donné
FP-3.0 | 2 | Allumer un voyant lumineux | 4 | Le voyant clairement visible | luminosité en candelas: 300 mcd | minimum 300 mcd | Le voyant luminant doit etre visible de tout les cotés
FP-3.1 | 2 | S'allumer en intervalle défini | 4 | Voyant lumineux s'allume en intervalle de 1 seconde | Intervalle: 1 sec | +1/0 sec
FP-3.0 | 2 | Allumer un voyant lumineux | 4 | Le voyant clairement visible | Distance: 1.5 m | Ouverte
FP-3.1 | 2 | S'allumer en intervalle défini | 4 | Voyant lumineux s'allume en intervalle de 1 seconde | précision du largage | Aucune | L'objet doit être deposer dans la zone avec une précision plus grande ou égale à celle de la zone cible
FP-3.2 | 2 | Être visible à distance | 3 | Le voyant est facilement visible à une distance de 1.5 m | 32 mm DIA et 130 mm LONG | +/- 10 mm par dimension
FP-4.0 | 2 | Manipuler une charge utile | 3 | Déposer l'objet dans un espace défini | Précision du largage | Aucune | L'objet doit être déposer dans la zone avec une précision plus grande ou égale à celle de la zone cible
FP-4.1 | 2 | Transporter un objet | 3 | Peut transporter un objet de forme cylindrique | 32mm DIA et 130mm LONG | +/- 10mm par dimension
FP-4.1 | 2 | Maintenir l'objet | 3 | Peut maintenir l'objet dans sa gueule | masse:30g minimum | aucune
FP-4.2 | 2 | Déposer un objet dans une zone prédéterminé | 3 | Déposer l'objet dans un espace défini | Cercle de rayon 5 cm | + 0/- 0.5 m
FP-5.0 | 2 | Battre de la queue | 4 | La queue bouge de gauche à droite de façon périodique | Cycle de 1 seconde (min 3 cycle) | Minimum 1 sec par cycle
FP-5.1 | 2 | Contrôler la cadence du battement | 4 | Durée du cycle de battement | 1 seconde | ≥ 1s
FP-5.2 | 2 | Maintenir l'amplitude de battement | 3 | Angle par rapport à la verticale | 45 degrés | ≥ 45 degrés
FP-6.0 | 2 | Démarrer via bouton/interrupteur | 4 | Bouton/interrupteur sur le robot-chien | Accès au bouton | Aucune | Le bouton doit être clairement accessible sur le robot

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
A N N E X E S

## Annexe B – Fonctions complémentaires (CdCF)

Cahier des charges fonctionnelles

MEC2105 – Projet Intégrateur II – Équipe 24 | Annexe B
No. | RÉV. | FONCTION | K | CRITÈRE | NIVEAU | FLEXIBILITÉ | COMMENTAIRES
FC | | Fonctions complémentaires
FC-1.0 | 1 | Completer le parcours bonus | 1 | Complèter les tâches du parcours bonus | temps de completion <30sec | Aucune | Dans le cas ou le robot est permis de faire le parcours bonus
FC-1.1 | 1 | Respecter l'intervalle de temps alloué | 1 | Interval de temps en seconde | 30s | 30s + 30s (au besoin)
FC-1.2 | 1 | Se réaligner vers X | 1 | Axe longitudinal du chien aligner vers le X | Diamètre du cercle autour du X | Aucune
FC-2.0 | 1 | Être facilement réparable | 2 | Pouvoir reparer les pièces cassées rapidement | 2h | ±20min | Durée estimé si des pièces de rechanges sont à disposition
FC-2.1 | 1 | Accessibilité des pièces | 2 | Acces facile au compartiment utile | Pourcentage du système accessible en cas de panne - 80% | +20%
FC-2.2 | 1 | Coût des réparations | 2 | Prix moyen de chaque réparation | 20-30$ | ±10$
FC-2.3 | 1 | Aisance de la réparation | 2 | Simplicité et independance des systèmes | | | Les systèmes sont facilement séparables les uns des autres
FC-3.0 | 1 | Maximiser l'efficience énergetique | 1 | Nombre de piles utilisées | maximum 2 pile | Aucune
FC-4.0 | 1 | Être esthétique | 3 | Nombre de fils apparents qui sont «flottants» ou non fixés | 0 | Aucune | Les fils électriques doivent être ou entièrement dissimulés, ou alors, si apparents, doivent être regroupés et fixés à une composante rigide du prototype (ne pas être «flottants»)
FC-4.1 | 1 | Ressembler à un chien | 3 | Avoir une tête et une queue | morphologie | Aucune | Le robot devra ressembler à la morphologie d'un chien
FC-5.0 | 1 | Être de construction recyclabe | 3 | Nombre d'utilisations avant besoin d'entretien ou réparation | 200 | ± 10 | Estimé
FC-6.0 | 1 | Être facilement rechargeable | 2 | Port de charge sur le chien-robot | Facilité d'accès des batteries ou du port de charge | Aucune
FC-7.0 | 1 | Être original | 2 | Unique dans ça conception et morphologie | N/A | N/A | Le robot est démarqué des autres
FC-8.0 | 1 | Optimiser le budget | 3 | Simplicité de la conception et matériaux non dispendieux | économie | | Le robot respect le budget avec une marge d'environ 20%
FC-9.0 | 1 | Stabilité du robot | 3 | Hauteur du centre de masse du robot | 25 cm de haut | ± 5 | Plus le centre de masse est bas, plus le robot est stable

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
A N N E X E S

## Annexe C – Contraintes (CdCF)

Cahier des charges fonctionnelles

MEC2105 – Projet Intégrateur II – Équipe 24 | Annexe C
No. | RÉV. | FONCTION | K | CRITÈRE | NIVEAU | FLEXIBILITÉ | COMMENTAIRES
CO | | Fonctions contraintes
CO-1.0 | 1 | Être léger | 4 | maximum : 1,5 kg | 3 | Maximum (+ 0, /- ouvert)
CO-2.0 | 1 | Être complètement autonome | 5 | Aucune intervention humaine | Aucune | Aucune
CO-3.0 | 1 | Respecter le budget | 3 | Maximum: 400$ | 400$ | Aucune
CO-4.0 | 1 | Completer le parcours obligatoire dans l'intervalle de temps alloué | 4 | Maximum: 120 s | 1 | Maximum (+ 0, /- ouvert)
CO-5.0 | 1 | Être sécuritaire | 5 | Nombre d'arêtes tranchantes | 0 | Aucune
| | | | Nombre de projectiles pouvant être projetés par le produit en opération | 0 | Aucune | Le produit doit être sécuritaire pour toute personne le manipulant ou se situant proche de lui
CO-6.0 | 1 | Être compact | 5 | Rentrer dans une cube de 30 cm x 30 cm x 45 cm | 2 | Maximum (+ 0, /- ouvert)
CO-7.0 | 1 | Respecter le nombre maximal de batterie rechargeable | 5 | 2 batteries 18650 de 3200 mAh et de 3,6-3,7 V | 1 | Maximum (+ 0, /- ouvert)
CO-8.0 | 1 | Fiabilité du programme informatique | 4 | Fonctionnement du code en fonction du nombre d'utilisation | 80% | (-10% ou +20%) | Le code devra fonctionner au moins 80% du temps

A
A

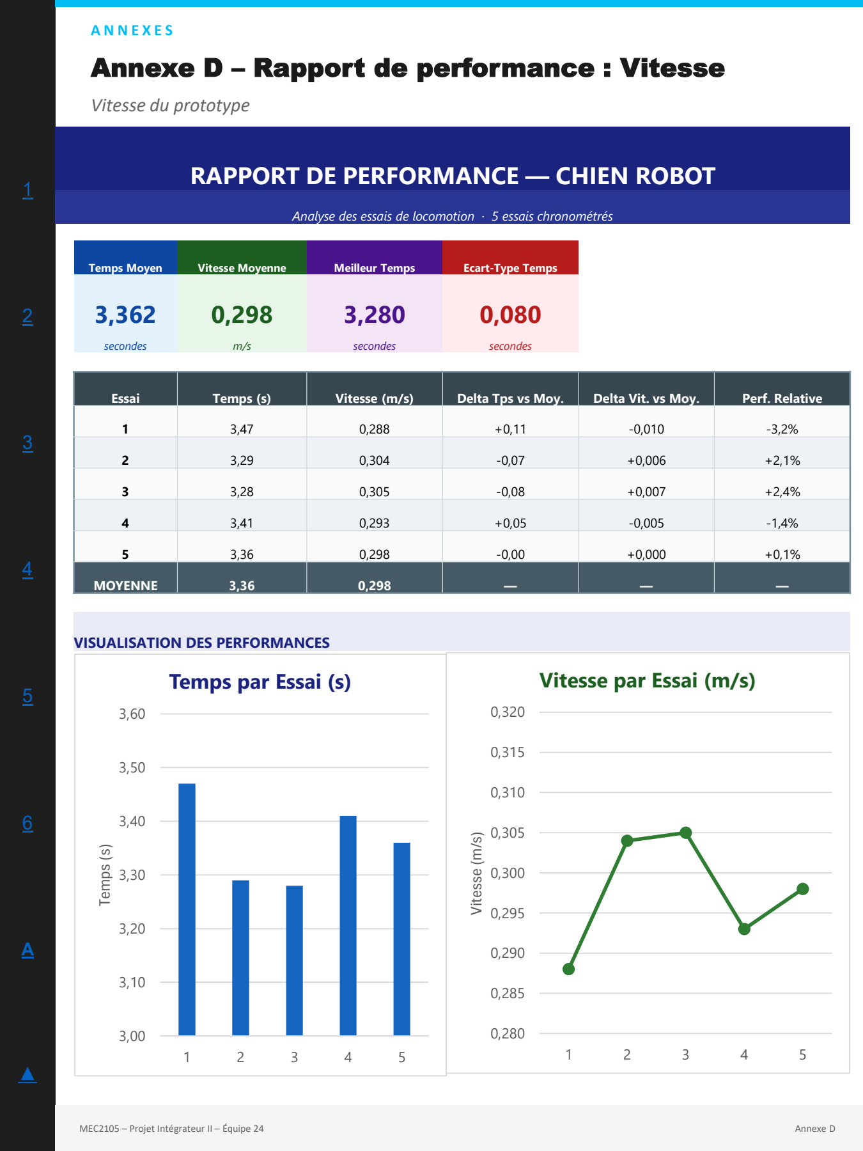
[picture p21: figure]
Vitesse du prototype; RAPPORT DE PERFORMANCE — CHIEN ROBOT; Temps Moyen; Vitesse Moyenne; Meilleur Temps; Ecart-Type Temps; secondes; Essai; Temps (s); Vitesse (m/s); Delta Tps vs Moy.; Delta Vit. vs Moy.; Perf. Relative; MOYENNE; VISUALISATION DES PERFORMANCES; Temps par Essai (s); Vitesse par Essai (m/s)

## Annexe D – Rapport de performance : Vitesse

MEC2105 – Projet Intégrateur II – Équipe 24 | Annexe D

Analyse des essais de locomotion · 5 essais chronométrés

## Annexe E – Rapport de performance : Battement de la queue

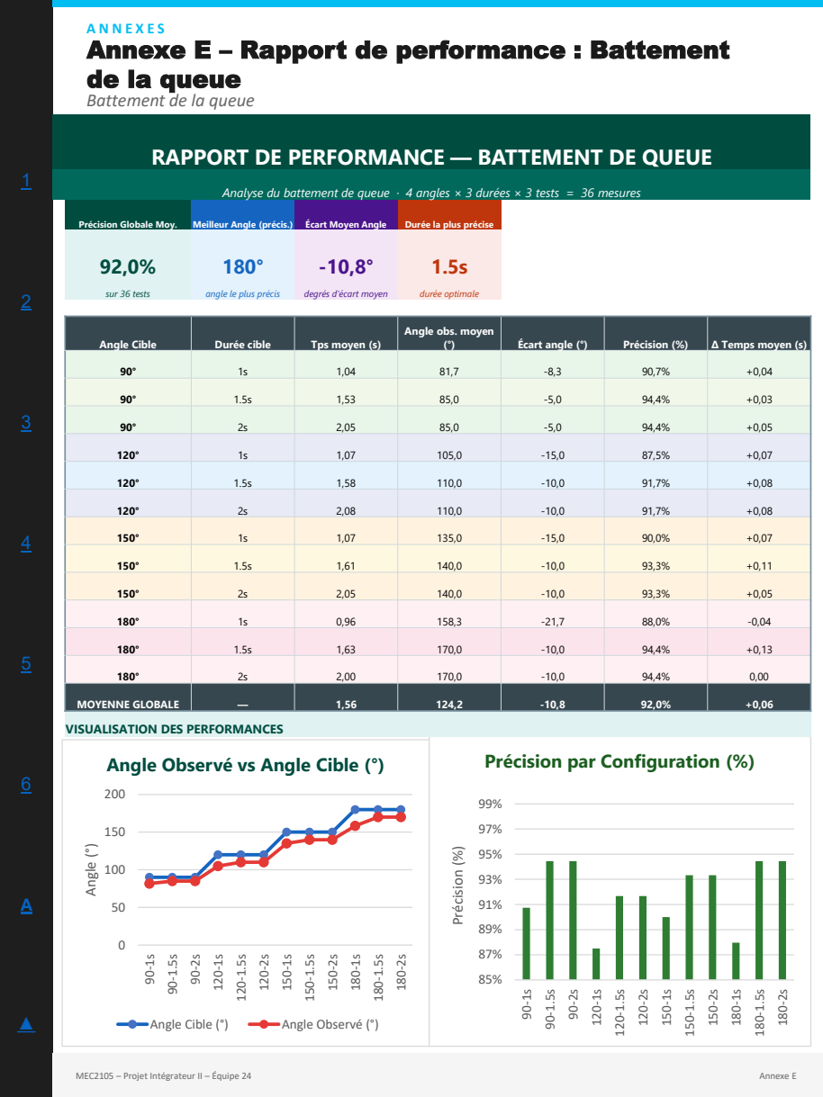
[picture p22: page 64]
MEC2105 – Projet Intégrateur II – Équipe 24; Annexe E; Angle (°); Angle Cible (°); Angle Observé (°); Précision (%); Précision Globale Moy.; Meilleur Angle (précis.); Écart Moyen Angle; Durée la plus précise; sur 36 tests; angle le plus précis; degrés d'écart moyen; durée optimale

Battement de la queue

RAPPORT DE PERFORMANCE — BATTEMENT DE QUEUE

Analyse du battement de queue · 4 angles × 3 durées × 3 tests = 36 mesures

Angle Cible | Durée cible | Tps moyen (s) | Angle obs. moyen (°) | Écart angle (°) | Précision (%) | Δ Temps moyen (s)

MOYENNE GLOBALE | — | 1,56 | 124,2 | -10,8 | 92,0% | +0,06

VISUALISATION DES PERFORMANCES
Angle Observé vs Angle Cible (°)

Précision par Configuration (%)

## Annexe F – Rapport de performance : Inclinaison tête

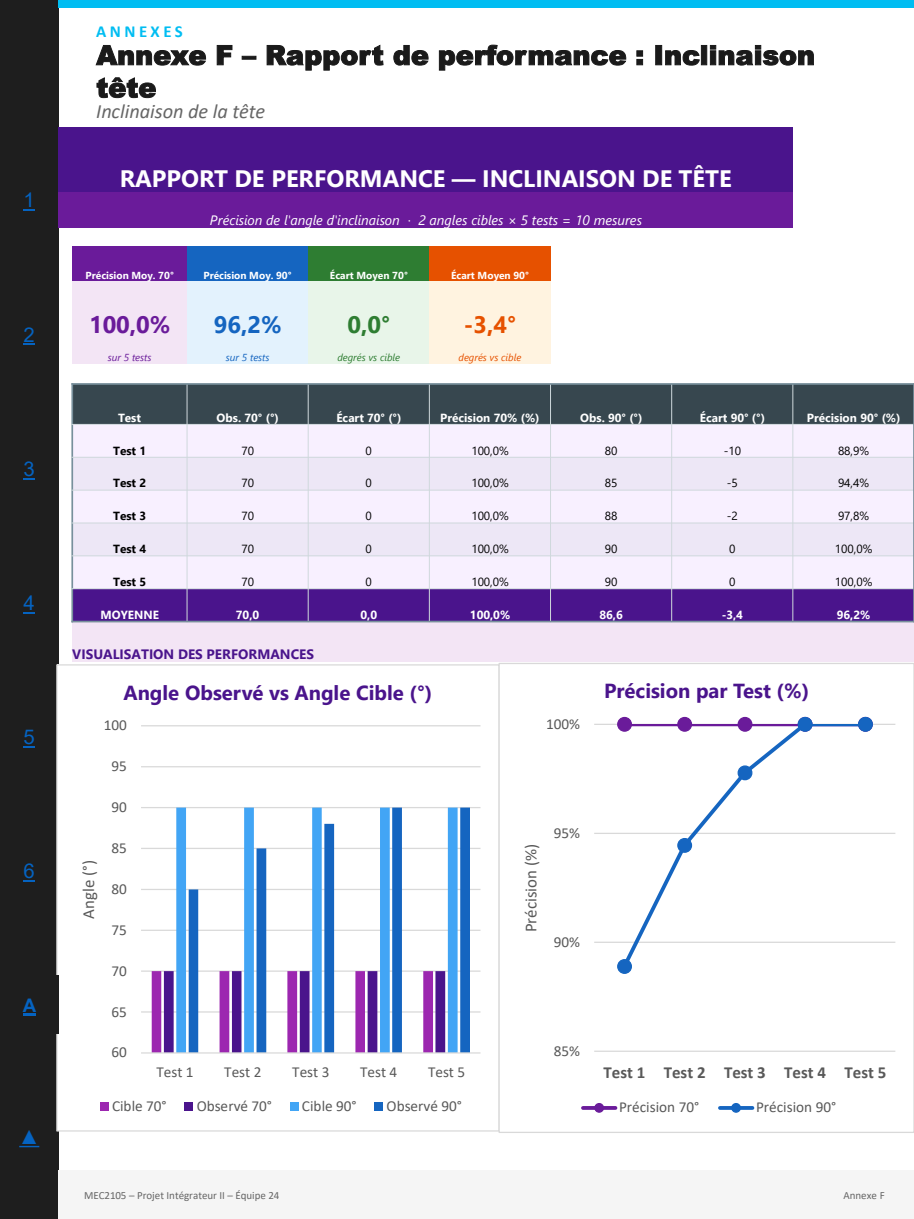
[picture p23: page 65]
MEC2105 – Projet Intégrateur II – Équipe 24; Annexe F; Précision Moy. 70°; Précision Moy. 90°; Écart Moyen 70°; Écart Moyen 90°; sur 5 tests; degrés vs cible; Test 1; Test 2; Test 3; Test 4; Test 5; Angle (°); Cible 70°; Observé 70°; Cible 90°; Observé 90°; Précision (%); Précision 70°; Précision 90°

Inclinaison de la tête

RAPPORT DE PERFORMANCE — INCLINAISON DE TÊTE

Précision de l'angle d'inclinaison · 2 angles cibles × 5 tests = 10 mesures

Test | Obs. 70° (°) | Écart 70° (°) | Précision 70% (%) | Obs. 90° (°) | Écart 90° (°) | Précision 90° (%)

Test 1 | 70 | 0 | 100,0% | 80 | -10 | 88,9%

Test 2 | 70 | 0 | 100,0% | 85 | -5 | 94,4%

Test 3 | 70 | 0 | 100,0% | 88 | -2 | 97,8%

Test 4 | 70 | 0 | 100,0% | 90 | 0 | 100,0%

Test 5 | 70 | 0 | 100,0% | 90 | 0 | 100,0%

MOYENNE | 70,0 | 0,0 | 100,0% | 86,6 | -3,4 | 96,2%

VISUALISATION DES PERFORMANCES
Angle Observé vs Angle Cible (°)

Précision par Test (%)

Test 1 Test 2 Test 3 Test 4 Test 5

1

2

3

4

5

6

A N N E X E S

## Annexe G – Rapport de performance : LED

Fonctionnement des LEDs

MEC2105 – Projet Intégrateur II – Équipe 24 | Annexe G

## RAPPORT DE VISIBILITÉ — COLLIER LED

Evaluation de 7 couleurs LED - 3 criteres - Point de vue enfant a 1m40

1ere couleur | 2eme couleur | 3eme couleur
Vert | Jaune | Cyan
Score : 3.50 / 5 | Score : 3.33 / 5 | Score : 3.00 / 5
Couleur | Rang | Confort visuel (/5) | Visibilite de face (/5) | Visibilite angle enfant (/5) | Score Moyen (/5)
Vert | 1 | 5,0 | 2,0 | 3,5 | 3,50
Jaune | 2 | 4,5 | 2,0 | 3,5 | 3,33
Cyan | 3 | 3,5 | 2,0 | 3,5 | 3,00
Blanc | 4 | 4,0 | 2,0 | 2,5 | 2,83
Rouge | 5 | 3,0 | 2,0 | 2,5 | 2,50
Bleu | 6 | 2,5 | 2,0 | 2,0 | 2,17
Magenta | 7 | 2,0 | 2,0 | 2,0 | 2,00

COMPARAISON PAR CRITERE

0 | 1 | 2 | 3 | 4 | 5

Vert

Jaune

Cyan

Blanc

Rouge

Bleu

Magenta

Note (/5)

Scores par Critere et par Couleur

Visibilite angle enfant | Visibilite face | Confort visuel

A
A

## Annexe H – Rapport de performance : Rotation

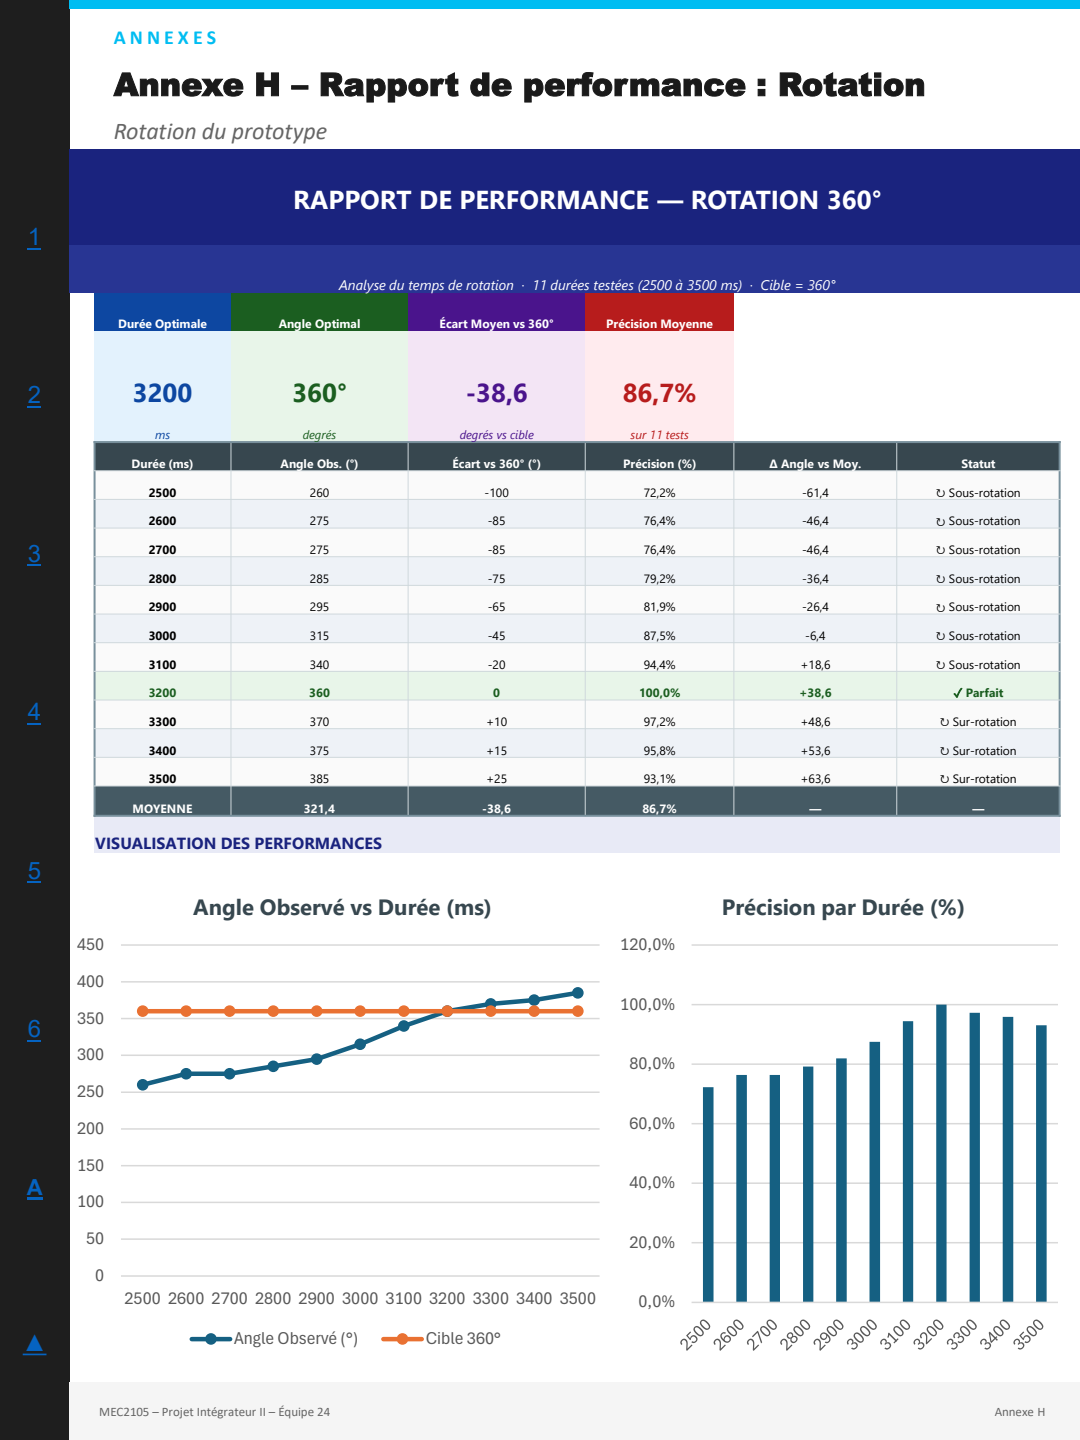
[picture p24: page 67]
MEC2105 – Projet Intégrateur II – Équipe 24; Annexe H; Durée Optimale; Angle Optimal; Écart Moyen vs 360°; Précision Moyenne; degrés; degrés vs cible; sur 11 tests; Angle Observé (°); Cible 360°

Rotation du prototype

RAPPORT DE PERFORMANCE — ROTATION 360°

Analyse du temps de rotation · 11 durées testées (2500 à 3500 ms) · Cible = 360°

Durée (ms) | Angle Obs. (°) | Écart vs 360° (°) | Précision (%) | Δ Angle vs Moy. | Statut

2500 | 260 | -100 | 72,2% | -61,4 | ↻ Sous-rotation

2600 | 275 | -85 | 76,4% | -46,4 | ↻ Sous-rotation

2700 | 275 | -85 | 76,4% | -46,4 | ↻ Sous-rotation

2800 | 285 | -75 | 79,2% | -36,4 | ↻ Sous-rotation

2900 | 295 | -65 | 81,9% | -26,4 | ↻ Sous-rotation

3000 | 315 | -45 | 87,5% | -6,4 | ↻ Sous-rotation

3100 | 340 | -20 | 94,4% | +18,6 | ↻ Sous-rotation

3200 | 360 | 0 | 100,0% | +38,6 | ✓ Parfait

3300 | 370 | +10 | 97,2% | +48,6 | ↻ Sur-rotation

3400 | 375 | +15 | 95,8% | +53,6 | ↻ Sur-rotation

3500 | 385 | +25 | 93,1% | +63,6 | ↻ Sur-rotation

MOYENNE | 321,4 | -38,6 | 86,7% | — | —

VISUALISATION DES PERFORMANCES

Angle Observé vs Durée (ms)

Précision par Durée (%)

1

2

3

4

5

6

ANNEXES

## Annexe I

Vidéos de validation

MEC2105 – Projet Intégrateur II – Équipe 24 | Annexe I

L’ensemble des essais de validation du prototype Le Dalmachien a été intégralement filmé afin de permettre une analyse rigoureuse a posteriori. Deux ressources vidéo sont mises à disposition :

### 1. Vidéo compilée des tests (< 2 min)

https://www.youtube.com/watch?v=ehKx_TYeKfc
Résumé de l’ensemble des essais réalisés en moins de 2 minutes.

### 2. Playlist YouTube – Tous les tests détaillés

https://youtube.com/playlist?list=PLbJqcXRQ_wBl3j-1xrZzBG9H-ZBKdkIiT Playlist contenant les vidéos détaillées de chaque essai individuel.

Tests couverts :
- Essai n°1 : Locomotion et immobilisation (vitesse)
- Essai n°2 : Battement de la queue
- Essai n°3 : Inclinaison de la tête
- Essai n°4 : Visibilité du voyant LED
- Essai n°5 : Rotation sur lui-même

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
A N N E X E S

## Annexe J – Nomenclature (BOM)

Liste des pièces – Chien Robot SSG

MEC2105 – Projet Intégrateur II – Équipe 24 | Annexe J.1
Identification (no de pièce) | Description | Dessin no | Matériau | Fournisseur et no. de pièce fournisseur | Masse unitaire (g) | Coût unitaire ($) | Référence assemblage ("Where-Used") | Qté totale | Masse totale (g) | Coût total ($)
ACH-001 | BASE DU CHÂSSIS | --- | ACIER | ABRA GK-KIT-TT04-BK | 180,00 | N/A | ASM-130 | 1 | 180,00 | ######
ACH-002 | MOTEUR TT | --- | --- | ABRA GK-KIT-TT04-BK | 20,00 | N/A | ASM-130 | 4 | 80,00
ACH-003 | PIGNON | --- | ACIER | ABRA GK-KIT-TT04-BK | 2,00 | N/A | ASM-130 | 4 | 8,00
ACH-004 | ROUAGE | --- | PLASTIQUE | ABRA GK-KIT-TT04-BK | 4,00 | N/A | ASM-130 | 4 | 16,00
ACH-008 | CHENILLE | --- | PLASTIQUE | ABRA GK-KIT-TT04-BK | 3,00 | N/A | ASM-130 | 2 | 6,00
ACH-005 | ARDUINO | --- | --- | ABRA A000066 | 65,00 | 30,00 | ASM-100 | 1 | 65,00 | 30,00
ACH-006 | MOTOR-DRIVER | --- | --- | ABRA WAVE-154 (ou eq) | 25,00 | 20,00 | ASM-100 | 1 | 25,00 | 20,00
ACH-007 | BATTERIES | --- | --- | ABRA BAT-18650-S35E-BP | 50,00 | 15,00 | ASM-100 | 2 | 100,00 | 30,00
ACH-008 | SERVO | --- | --- | ABRA FS90 (ou eq) | 10,00 | 10,00 | ASM-110 | 3 | 30,00 | 30,00
CUS-001 | TÊTE | C001 | PLA | CUSTOM | 132,00 | 17,16 | ASM-120 | 1 | 132,00 | 17,16
CUS-002 | ÉTAGE | C002 | PLA | CUSTOM | 75,00 | 9,75 | ASM-130 | 1 | 75,00 | 9,75
CUS-003 | CORPS | C003 | PLA | CUSTOM | 65,35 | 8,50 | ASM-100 | 1 | 65,35 | 8,50
CUS-004 | CORPS-MIRROIR | C004 | PLA | CUSTOM | 65,50 | 8,52 | ASM-100 | 1 | 65,50 | 8,52
CUS-005 | Fixation | C005 | PLA | CUSTOM | 33,50 | 4,36 | ASM-110 | 3 | 100,50 | 13,07
CUS-006 | QUEUE | C006 | PLA | CUSTOM | 17,00 | 2,21 | ASM-140 | 1 | 17,00 | 2,21
STAND-001 | M4 x 50 BOLT | STD | ACIER | McMaster 91290A193 (ou eq) | 13,20 | 0,75 | ASM-130 | 4 | 52,80 | 3,00
STAND-002 | M4 HEX NUT | STD | ACIER | McMaster 94168A111 (ou eq) | 0,80 | 0,35 | ASM-130 | 12 | 9,60 | 4,20
STAND-003 | M3 HEX NUT | STD | ACIER | McMaster 90370A203 (ou eq) | 0,40 | 0,40 | ASM-100 | 20 | 8,00 | 8,00
STAND-004 | M3 x 30 BOLT | STD | ACIER | McMaster 92095A185 (ou eq) | 2,00 | 0,2 | ASM-130 | 8 | 16,00 | 1,60
STAND-006 | M3 x 20 BOLT | STD | ACIER | McMaster 92095A187 (ou eq) | 1,40 | 0,25 | ASM-100 | 12 | 16,80 | 3,00
| | | | | | | | TOTAL: | 1068,55 | 234,00

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
A N N E X E S

## Annexe J.2 – BOM ASM-100 : Chien Robot

Assemblage principal – 13 composantes

MEC2105 – Projet Intégrateur II – Équipe 24 | Annexe J.2
No | Qté | Identification (no de pièce) | Description | Dessin no | Matériau | Fournisseur et no. de pièce fournisseur | Masse unitaire (g) | Coût unitaire ($) | Masse totale (g) | Coût total ($)
1 | 1 | ASM-120 | S-ASM TETE | ASM120 | --- | --- | 219,00 | 41,87 | 219,00 | 41,87
2 | 1 | ASM-130 | S-ASM CHASSI | ASM130 | --- | --- | 290,00 | 45,00 | 290,00 | 45,00
3 | 1 | ASM-140 | S-ASM QUEUE | ASM140 | --- | --- | 60,50 | 14,57 | 60,50 | 14,57
4 | 1 | CUS-002 | ÉTAGE | C002 | ACRYLIQUE | CUSTOM | 75,00 | 9,75 | 75,00 | 9,75
5 | 1 | CUS-003 | CORPS | C003 | ACIER | CUSTOM | 65,35 | 8,50 | 65,35 | 8,50
6 | 1 | CUS-004 | CORPS-MIRROIR | C004 | ALUMINIUM | CUSTOM | 65,50 | 8,52 | 65,50 | 8,52
7 | 4 | STAND-001 | M4 x 50 BOLT | STD | ACIER | McMaster 91290A193 (ou eq) | 13,20 | 0,75 | 52,80 | 3,00
8 | 12 | STAND-002 | M4 HEX NUT | STD | ACIER | McMaster 94168A111 (ou eq) | 0,80 | 0,35 | 9,60 | 4,20
9 | 20 | STAND-003 | M3 HEX NUT | STD | ACIER | McMaster 90370A203 (ou eq) | 0,40 | 0,40 | 8,00 | 8,00
10 | 12 | STAND-006 | M3 x 20 BOLT | STD | ACIER | McMaster 92095A187 (ou eq) | 1,40 | 0,25 | 16,80 | 3,00
11 | 1 | ACH-005 | ARDUINO | --- | --- | AMAZON | 65,00 | 30,00 | 65,00 | 30,00
12 | 1 | ACH-006 | MOTOR-DRIVER | --- | --- | AMAZON | 25,00 | 20,00 | 25,00 | 20,00
13 | 1 | ACH-007 | BATTERIES | --- | --- | AMAZON | 50,00 | 15,00 | 50,00 | 15,00
| TOTAL: | | | | | | | | 1002,55 | 211,40

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
A N N E X E S

## Annexe J.3 – BOM ASM-110 : Sous-assemblage Servo

2 composantes – Masse totale : 43,5 g

MEC2105 – Projet Intégrateur II – Équipe 24 | Annexe J.3
No | Qté | Identification (no de pièce) | Description | Dessin no | Matériau | Fournisseur et no. de pièce fournisseur | Masse unitaire (g) | Coût unitaire ($) | Masse totale (g) | Coût total ($)
1 | 1 | CUS-005 | FIXATION | C005 | PLA | CUSTOM | 33,50 | 4,36 | 33,50 | 4,36
| 1 | ACH-008 | SERVO | N/A | N/A | AMAZON | 10 | 8 | 10,00 | 8,00
| TOTAL: | | | | | | | | 43,50 | 12,36

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
A N N E X E S

## Annexe J.4 – BOM ASM-120 : Sous-assemblage Tête

2 composantes – Masse totale : 219 g

MEC2105 – Projet Intégrateur II – Équipe 24 | Annexe J.4
No | Qté | Identification
| | (no de pièce) | Description | Dessin no | Matériau | Fournisseur et no. de pièce fournisseur | Masse unitaire (g) | Coût unitaire ($) | Masse totale (g) | Coût total ($)
| 2 | ASM-110 | S-ASM SERVO | ASM110 | N/A | --- | 43,50 | 12,36 | 87,00 | 24,71
2 | 1 | CUS-001 | TETE | CUS-001 | PLA | CUSTOM | 132,00 | 17,16 | 132,00 | 17,16
| TOTAL: | | | | | | | | 219,00 | 41,87

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
A N N E X E S

## Annexe J.5 – BOM ASM-130 : Sous-assemblage Châssis

5 composantes – Masse totale : 290 g

MEC2105 – Projet Intégrateur II – Équipe 24 | Annexe J.5
No | Qté | Identification (no de pièce) | Description | Dessin no | Matériau ACIER | Fournisseur et no. de pièce fournisseur | Masse unitaire (g) | Coût unitaire ($) | Masse totale (g) | Coût total ($)
1 | 1 | ACH-001 | BASE DU CHÂSSIS | --- | | ABRA GK-KIT-TT04-BK | 180,00 | N/A | 180,00 | 45,00 $
2 | 4 | ACH-002 | MOTEUR TT | --- | --- | ABRA GK-KIT-TT04-BK | 20,00 | N/A | 80,00
3 | 4 | ACH-003 | PIGNON | --- | ACIER | ABRA GK-KIT-TT04-BK | 2,00 | N/A | 8,00
4 | 4 | ACH-004 | ROUAGE | --- | PLASTIQUE | ABRA GK-KIT-TT04-BK | 4,00 | N/A | 16,00
5 | 2 | ACH-008 | CHENILLE | --- | PLASTIQUE | ABRA GK-KIT-TT04-BK | 3,00 | N/A | 6,00
| TOTAL: | | | | | | | | 290,00 | 45,00

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
A N N E X E S

## Annexe J.6 – BOM ASM-140 : Sous-assemblage Queue

2 composantes – Masse totale : 60,5 g

MEC2105 – Projet Intégrateur II – Équipe 24 | Annexe J.6
No | Qté | Identification
| | (no de pièce) | Description | Dessin no | Matériau | Fournisseur et no. de pièce fournisseur | Masse unitaire (g) | Coût unitaire ($) | Masse totale (g) | Coût total ($)
| 1 | ASM-110 | S-ASM SERVO | ASM110 | N/A | --- | 43,50 | 12,36 | 43,50 | 12,36
2 | 1 | CUS-006 | QUEUE | C006 | PLA | CUSTOM | 17,00 | 2,21 | 17,00 | 2,21
| TOTAL: | | | | | | | | 60,50 | 14,57

1

A
A

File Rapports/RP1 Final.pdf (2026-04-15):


MEC2105 – Projet Intégrateur 2 Groupe-cours no 02

ROBOT CHIEN
Rapport 1

Présenté à
DI PIETRO Vincent, Ing.

par l’équipe no 24

MELANÇON, Rose

LECLERC-KO, LILIANE

EL AZOURY, Miguel

LALONDE, William

KANGUE ESSOME SIMEU, Ryan

BOUADDI, Adam


_________________________ _________________________ _________________________ _________________________ _________________________ _________________________ Le 01 février 2026

à Montréal

ii

Résumé

Le projet étudié dans ce rapport traite de la création d’un chien-robot autonome qui offre un stimulus modéré pouvant servir à enrichir l’apprentissage d’élèves atteints de troubles comme le TSA. Le client, l’École régionale du Vent-Nouveau, veut en effet améliorer l’apprentissage de ses étudiants. Le but premier de ce rapport était de déterminer les principales demandes du client et d’ainsi commencer à conceptualiser une solution. À cette fin, une analyse détaillée des besoins du client a été faite, permettant ainsi l’écriture d’un premier cahier des charges.

Dans un premier temps, l’analyse des besoins a révélé que le jouet chien-robot devrait remplir plusieurs critères, parmi les plus importants : le jouet doit être entièrement autonome, doit simuler le comportement d’un vrai chien en interagissant avec l’élève et, enfin, ne doit pas mener à la surstimulation de l’utilisateur. En ce qui a trait au cahier des charges, les principales fonctions du chien-robot sont d’abord celles de pouvoir se mouvoir sur une surface plane et de procurer une stimulation suffisante aux élèves à travers des actions comme battre la queue, allumer son collier ou encore transporter un jouet. Les dimensions du dispositif en question sont telles qu’il puisse être confiné dans un cylindre de 15 cm de rayon, au maximum, et de 45 cm de hauteur. Quant au coût de fabrication d’un seul exemplaire, il ne doit pas dépasser 400 $. Finalement, l’entièreté des systèmes du chien-robot devra être alimentée par, au maximum, deux batteries de type 18650 de 3200 mAh / 3,7 V.

Après l’établissement du cahier des charges, six concepts préliminaires ont été proposés, montrant diverses manières de remplir les fonctions principales tout en respectant les contraintes du projet. Ces fonctions ont été utilisées, parmi d’autres critères, dans la matrice de Pugh pour discriminer les concepts les plus prometteurs. Ce processus a permis de retenir trois concepts prometteurs : un concept sur chaîne, un autre sur roues et, enfin, un autre sur roues et billes multidirectionnelles. La phase préliminaire ayant été complétée, les prochains objectifs seront de débuter le développement de la solution, principalement en déterminant les moyens à utiliser pour la conception de ce jouet.

Mots clés : École, étudiant, TSA, robot-chien, stimulation, autonomie.

iii

Table des matières

Page

iv

v

Liste des figures

vi

Liste des tableaux

7

Introduction

Le projet présenté dans ce rapport porte sur la conception d’un chien-robot autonome visant à offrir un stimulus modéré pouvant contribuer à enrichir l’apprentissage d’élèves présentant notamment un trouble du spectre de l’autisme (TSA). Le client, l’École régionale du Vent-Nouveau, souhaite améliorer l’expérience d’apprentissage de ses élèves à l’aide d’un dispositif interactif adapté.

L’objectif principal de ce rapport est d’identifier clairement les demandes du client, puis d’amorcer la conceptualisation d’une solution en les traduisant en exigences. À cette fin, une analyse détaillée des besoins a été réalisée, menant à l’élaboration d’un premier cahier des charges.

Le chapitre 1 présente la définition du projet, l’analyse des besoins et l’analyse fonctionnelle. Le chapitre 2 expose les premières idées de concepts ainsi que le processus ayant mené à leur raffinement. Le cahier des charges complet, ainsi que le processus de gestion d’équipe, sont fournis en Annexe A.

### 1. Contexte, besoins du client et cahier des charges

### 1.1 Définition du projet

L’École régionale du Vent-Nouveau est une école secondaire spécialisée qui accueille environ 130 élèves multihandicapés âgés de 12 à 21 ans, présentant des déficiences moyennes à sévères avec troubles associés, notamment le trouble du spectre de l’autisme (TSA). Ces élèves proviennent principalement de plusieurs commissions scolaires de la région du Grand Montréal. Grâce à des installations ultraspécialisées, l’école offre des programmes et des services adaptés à leurs besoins.

Dans une démarche d’amélioration continue, l’école souhaite intégrer davantage d’activités exposant les élèves à des stimuli visuels, tout en évitant la surstimulation. Il est également essentiel que ces activités requièrent peu d’interactions et d’interventions manuelles, et qu’elles permettent la mise en place de routines stables. L’école désire en outre mettre à profit les centres d’intérêt de ses élèves, notamment leur attrait pour les animaux et, en particulier, pour les chiens.

8

Toutefois, l’école ne dispose pas du budget nécessaire pour acquérir une solution commerciale répondant à ces objectifs. Dans ce contexte, Polytechnique Montréal, dans le cadre du cours MEC2105 (Projet intégrateur II), mandate des équipes d’étudiants pour concevoir et fabriquer un chien-robot autonome. Le prototype devra être capable de se déplacer sur un parcours prédéterminé et d’exécuter des mouvements routiniers tout en fournissant un niveau de stimuli visuels compatible avec la clientèle visée. À la fin du projet, les prototypes réalisés seront remis à l’École régionale du Vent-Nouveau afin que ses élèves puissent en bénéficier.

### 1.2 Analyse des besoins du client

Dans le cadre de l’amélioration de ses activités éducatives, le client souhaite intégrer davantage d’activités reposant sur des stimuli visuels, à condition que ceux-ci demeurent contrôlés et ne provoquent pas de surstimulation. Un autre besoin central est de limiter au maximum les interactions et interventions manuelles requises pendant l’activité, afin de privilégier des routines stables et répétables qui renforcent le sentiment de confort et de sécurité des élèves.

L’analyse de la situation actuelle met en évidence plusieurs lacunes : certaines activités disponibles ou inspirantes demandent trop d’interventions de la part des élèves, sont trop rapides, ne favorisent pas l’instauration de routines, ou comportent des stimuli visuels et sonores trop intenses. De plus, bien que des chiens-robots existent sur le marché et soient performants d’un point de vue technique, ils sont généralement conçus pour une interaction soutenue avec l’utilisateur et peuvent présenter une intensité de stimulation (vitesse, sons, lumières) peu compatible avec la clientèle visée. Enfin, les contraintes budgétaires de l’établissement rendent difficile l’acquisition d’une solution commerciale qui satisferait simultanément l’ensemble de ces exigences.

Ces constats se traduisent en besoins explicites pour la solution à développer : le prototype doit offrir des stimuli visuels modérés, être entièrement autonome (sans télécommande) et exécuter une séquence d’actions routinières, tout en conservant une apparence inspirée de la morphologie d’un chien pour maximiser l’adhésion des élèves. Sur le plan fonctionnel, le robot doit être capable de se déplacer

9

et de tourner sur une piste, de déposer un jouet dans une zone cible, puis de produire des signaux visuels (clignotement du collier) et un mouvement répétitif (battement de la queue) dans un temps imposé. Un parcours optionnel (bonus) pourra être réalisé si la configuration retenue le permet.

Tableau 1.2.1 - Synthèse des besoins et niveau d’importance

Importance élevée :

- Transporter un jouet poulet et le déposer dans la zone bleue du parcours obligatoire.
- Battre de la queue.
- Avoir un collier qui allume (LED)
- Minimiser le poids et la grosseur du robot chien.
- Exécuter le parcours de façon autonome.
- Être réparable, démontable et robuste pour favoriser une seconde vie.

Importance moyenne :

- Optimiser l’apparence.
- Minimiser le temps de déplacement entre les différents arrêts.
- Minimiser le bruit.

Importance faible :

- Réaliser le parcours facultatif.

10

### 1.3 Cahier des charges fonctionnel

Les fonctions qui découlent de l’analyse du besoin ont été synthétisées dans un cahier des charges. Ce dernier est représenté de manière simplifiée ci-dessous, le cahier des charges complet étant en annexe.

Tableau 1.3.1 – Synthèse du cahier des charges fonctionnelles

No. | RÉV. | FONCTION | K | CRITÈRE | NIVEAU | FLEXIBILITÉ | COMMENTAIRES
FP | Fonctions principales
FP-1.0 | 2 | Se déplacer | 5 | Bouger sur à travers la piste sans franchir la zone limite | Dimensions de la piste | Aucune | Évaluation de la facilité avec laquelle le robot peut se déplacer
FP-3.0 | 2 | Allumer un voyant lumineux | 4 | Le voyant clairement visible | Luminosité en candelas: 300 mcd | Minimum 300 mcd | Le voyant luminant doit être visible de tous les cotés
FP-4.0 | 2 | Manipuler la charge utile | 3 | Déposer l'objet dans un espace défini | Précision du largage | Aucune | L'objet doit être déposer dans la zone avec une précision plus grande ou égale à celle de la zone cible
FP-5.0 | 2 | Battre de la queue | 4 | La queue bouge de gauche à droite de façon périodique | Cycle de 1 seconde (min 3 cycle) | Minimum 1 sec par cycle
FP-6.0 | 2 | Démarrer via bouton/interrupteur | 4 | Bouton/interrupteur sur le robot-chien | Accès au bouton | Aucune | Le bouton doit être clairement accessible sur le robot
FC | Fonctions complémentaires
FC-1.0 | 1 | Compléter le parcours bonus | 1 | Compléter les tâches du parcours bonus | Temps de complétion <30sec | Aucune | Dans le cas où le robot est permis de faire le parcours bonus
FC-2.0 | 1 | Être facilement réparable | 2 | Pouvoir réparer les pièces cassées rapidement | 2h | ±20min | Durée estimée si des pièces de rechanges sont à disposition

11

FC-

5.0 | 1 | Être facilement
rechargeable | 2

Port de charge sur le
chien-robot

Facilité
d'accès des
batteries
ou du port
de charge

Aucune

CO | Fonctions contraintes
CO-2.0 | 1 | Être complètement autonome | 5 | Aucune intervention humaine | Aucune | Aucune
CO-4.0 1 | | Compléter le parcours obligatoire dans l'intervalle de temps alloué | 4 | Maximum: 120 s | 1 | Maximum (+ 0, /- ouvert)
CO-6.0 | 1 | Être compact | 5 | Rentrer dans un cube de 30 cm x 30 cm x 45 cm | 2 Maximum (+ 0, | /- ouvert)
CO-7.0 1 | | Respecter le nombre maximal de batterie rechargeable | 5 | 2 batteries 18650 de 3200 mAh et de 3,6-3,7 V | 1 Maximum (+ 0, | /- ouvert)

La méthodologie retenue pour construire le cahier des charges repose sur une analyse fonctionnelle. Les besoins essentiels du client sont regroupés en fonctions principales, c’est-à-dire celles qui déterminent directement si la solution répond au mandat. Chaque fonction principale se voit attribuer un facteur d’importance K de 1 à 5 (ordre croissant) afin de rendre explicites les priorités. Lorsque la portée d’une fonction est trop large, elle est déclinée en sous-fonctions pour clarifier l’attendu et éviter les interprétations.

Les fonctions complémentaires rassemblent ensuite les éléments non obligatoires, mais souhaitables, qui améliorent la qualité d’usage ou la valeur de la solution. Les contraintes du projet sont listées séparément, puisqu’elles s’appliquent à l’ensemble du système (ex. budget, masse, autonomie, intégration) et encadrent toutes les décisions de conception.

Enfin, pour que le cahier des charges soit réellement exploitable, chaque fonction est associée à un critère d’évaluation (mesurable ou au minimum observable) ainsi qu’à une méthode de validation définie (mesures, essais, scénario de test ou démonstration). Cela permet de vérifier de façon objective, au fil du développement, que les exigences sont respectées.

12

### 2. Développement des concepts préliminaires

### 2.1 Idées

### 2.1.1 Brevet

Un brevet pertinent pour le projet est celui de Mitsuba Corporation, portant sur un moteur d’essuie-glace intégrant un mécanisme de réduction et un système de bielle-manivelle. Ce type d’architecture permet de convertir la rotation du moteur en un mouvement oscillatoire (aller-retour) à la sortie. Le principe est directement transposable au battement de la queue : en fixant un bras de levier sur l’arbre de sortie (ou sur la bielle), la queue peut être entraînée en oscillation avec une amplitude contrôlée. La fréquence des battements se règle ensuite par la vitesse d’entraînement du moteur (ou par la commande), ce qui permet d’ajuster facilement le mouvement pour respecter les spécifications associées à la fonction.

Figures 2.1.1.1 - Brevet Mitsuba : mécanisme d’essuie-glace et adaptation pour la queue


### 2.1.2 Matrice morphologique

Dans un premier temps, l’analyse des besoins a mené à l’établissement d’une liste structurée de fonctions principales, de fonctions complémentaires et de contraintes, qui a servi de base à la génération

13

d’idées. Pour chacune des fonctions, une séance de brainstorming a ensuite permis de proposer plusieurs pistes de solution et d’alimenter la matrice morphologique.

À partir de cette matrice, différents concepts ont été construits en sélectionnant et en combinant une option par fonction. Cette étape permet de générer plusieurs solutions distinctes, tout en s’assurant que chaque concept couvre l’ensemble des fonctions nécessaires et respecte les contraintes du projet. Les concepts obtenus répondent ainsi aux besoins exprimés par le client, mais avec des architectures et des choix techniques différents, ce qui facilite la comparaison et la sélection d’une configuration à approfondir.

Tableaux 2.1.2.1 – Matrice Morphologique


Se déplacer

Transporter un objet

Faire clignoter une lumière

Déposer un objet

Battre de la queue

14

### 2.2 Tableau synthèse et description de 6 concepts préliminaires

Tableau 2.2.1 - Synthèse et description de 6 concepts préliminaires

Nom du concept +
concepteur
Description | Croquis

Le chien Cadeau, Rose
Melançon

Ce concept est composé de quatre roues entraînées par des moteurs, ce qui lui permet d’avancer. Il possède une boucle ajourée intégrant des LED, afin de réduire le poids total. La bouche fonctionne grâce à des plaques munies de petites dents qui retiennent le jouet « poulet ». La plaque inférieure se déplace pour libérer le contenu de la gueule. Un panneau latéral s’ouvre pour donner accès aux mécanismes et faciliter la réparation. Enfin, un bouton permet de mettre le robot en marche.

Liste des pièces:

1 - Roues

2 - Plaques pivotantes

3 - Queue

4 - Boucle

5 - LED

6 - Dents

7 - Trappe

15

CHIHUAHUA, Ryan
Kangue

Ce concept fonctionne avec deux roues avant, chacune entraînée par un moteur à courant continu, tandis qu’une roue arrière assure le guidage. Les pinces effectuent un mouvement de rotation grâce à un ensemble d’engrenages entraîné par un servomoteur. De façon similaire, la queue se déplace également en rotation, mais elle est reliée directement à son servomoteur par une liaison fixe. Enfin, la carte Arduino, le câblage électrique, la LED et les piles seront solidement fixés sur le corps du robot.

Liste des pièces

- 1 Roue directrice
- 2 Roues motrices
- 3 Engrenages
- 2 moteurs à courant continu
- 2 moteur Servo
- 1 Lumière LED
- 1 Circuit Arduino
- 1 Pile
- Fils électriques


CHIEN MINECRAFT,
Liliane Leclerc-Ko

Ce concept est un chien inspiré de Minecraft. Il comporte des pattes non articulées, une gueule mobile en une seule pièce, un servomoteur pour

16

faire battre la queue, ainsi qu’une bande LED intégrée au corps du chien.

Liste de pièces :

1 - Bande LED intégrée au corps

2 - circuit Arduino

3 - Gueule en une pièce qui tourne

4 - jambes sans articulations motorisées

5 - Servo moteur pour la queue

Chien-Robot SSG,
William Lalonde

SSG signifie « sausage », soit « saucisse » en français, en référence à son apparence de chien saucisse. Le robot est propulsé par un système de type roues-chenilles. Sa mâchoire inférieure, maintenue par un ressort de torsion, s’ouvre grâce à un fil enroulé sur une bobine entraînée par un moteur électrique. Son collier comporte une DEL, et sa queue bat à l’aide d’un mécanisme de manivelle actionné par un autre moteur électrique.


Liste de pièces:

1 - Système style roue-chenilles

2 - Mâchoire inférieure motorisé

3 - 4 pattes décoratives

4 - 2 oreilles décoratives

5 - Collier avec médaille DEL

17

6 - Couvercle amovible

7 - Mécanisme de queue battante

8 - Bouton démarreur

Chien-Robot SSG V2,
William Lalonde

Une version alternative du Robot-Chien SSG, dont la morphologie reste très similaire à la version précédente. Les différences se trouvent surtout au niveau des mécanismes. La mâchoire est à cliquet : elle se ferme manuellement, puis s’ouvre grâce à un actionneur qui déclenche le cliquet. La propulsion se fait par un système de roues de style « train ». Le collier est une bande DEL, et la queue peut battre grâce à l’action combinée d’un servomoteur et d’un ressort de torsion au niveau de son pivot.


Liste de pièces:

1 - Mécanisme de propulsion style “roues de train”

2 - Collier en bande de DEL

3 - Système de queue battante

4 - Interrupteur démarreur

5 - Mâchoire à cliquet à actuateur pour le déclic

6 - 4 pattes décoratives

7 - oreilles décoratives

8 - 2 trappes ouvrantes pour la maintenance

18

Le Z-Neck, Adam
Bouaddi

Chien-robot autonome sur châssis roulant. Dépôt du jouet assuré par un bras articulé repliable intégré à la tête (cinématique type Z). Transport en gueule, puis ouverture de la mâchoire inférieure pour relâcher le jouet en zone cible. Locomotion par 2 roues motrices en diagonale pour faciliter la rotation, avec pieds inclinés pour améliorer la stabilité à l’accélération.


Liste de pièces :

1 – Chassis

2 – Coque / Habillage « chien »

3 – 2 roues motrices

4 – Roue-bille omnidirectionnelle

5 – 2 moteurs / motoréducteurs de tractions

7 – Sous-ensemble du bras articulé

8 – Bande LED


C.R.A.P.E.A.U.

Le C.R.A.P.E.A.U. est un chien-robot quadrupède monté sur roues. Il possède huit roues, disposées par paires au niveau de chaque patte. Les roues motrices sont placées en diagonale (patte avant gauche et patte arrière droite). Le mouvement est transmis des moteurs aux roues à

19

l’aide d’un système chaîne–roue


dentée jouant le rôle de réducteur, ce qui augmente le couple disponible. La mâchoire est rotative de façon à ce que seule la partie inférieure simule une mandibule de chien. Enfin, la queue est montée directement sur l’arbre d’un moteur, ce qui lui permet de battre en cycles.

Des indications complémentaires pour les concepts C.R.A.P.E.A.U. et CHIHUAHUA sont disponibles aux Annexes B et C.

### 2.3 Matrice de Pugh

3. Les fonctions qui se trouvent dans la matrice de Pugh ont majoritairement été choisies parmi celles se trouvant dans le cahier de charge et qui sont jugées comme les plus déterminantes pour la réussite du projet. Lors de la délibération pour les trois concepts retenus, le concept no 6 est le seul qui a automatiquement été écarté, dû à son pointage pondéré très faible. Quant aux autres, ils ont été jugés par rapport à leur pointage pondéré, tout en laissant la discrétion à l’équipe de prendre un choix logique selon d’autres paramètres, comme leur pointage brut. En somme, les deux concepts avec les plus hauts pointages pondérés ont été choisis, soit le Chien-Robot SSG V2 et le CRAPEAU. Le troisième concept choisi a été le NO 5, avec le quatrième pointage pondéré le plus haut et le troisième pointage brut plus élevé. Une version détaillée de l’attribution des points de la matrice Pugh se trouve à l’annexe H.

20

Figure 2.3.1 – Matrice de Pugh


### 2.4 Description des 3 concepts présélectionnés

Premier concept

Le concept proposé est un chien-robot autonome dont la tête est portée par un bras articulé repliable, conçu pour saisir le jouet « poulet », le transporter, puis le déposer de façon contrôlée dans la zone cible, tout en conservant une apparence explicite de chien et une locomotion sur roues. L’architecture regroupe un châssis roulant intégrant l’alimentation, l’électronique (Arduino) et les actionneurs de locomotion, un module « tête–gueule » monté à l’avant sur un bras articulé, ainsi qu’une queue articulée à l’arrière. Le collier lumineux est réalisé par une bande LED placée près de la tête afin de rester visible depuis la position de l’élève (point X) sans être obstruée.

21

La manipulation est assurée par la gueule intégrée à la tête, qui maintient le jouet pendant le déplacement et le libère au dépôt. Le bras articulé offre deux configurations : repliée pour réduire l’encombrement durant le trajet et respecter la contrainte de départ, puis déployée pour amener la tête au-dessus de la zone de dépôt. La cinématique de la gueule respecte la contrainte d’ouverture/fermeture uniquement selon une direction verticale. Le bras permet aussi un léger repositionnement au moment du dépôt afin d’augmenter la répétabilité et de limiter les risques d’accrochage ou de dépôt partiel.

La locomotion repose sur deux roues motorisées à l’avant, chacune entraînée par un moteur, tandis qu’une roue-bille centrale à l’arrière assure la stabilité et le guidage. Des pattes décoratives latérales complètent l’esthétique « chien » sans contribuer à l’appui au sol, ce qui simplifie la cinématique tout en conservant une manœuvrabilité adéquate sur la piste. La séquence visée est la suivante : départ avec le jouet en gueule, déplacement jusqu’à la zone de dépôt, unique tentative de dépôt par ouverture de la gueule, puis exécution des actions demandées aux emplacements requis après orientation vers X (clignotement de la bande LED en trois cycles, puis battement de queue en trois cycles avec amplitude minimale de 45° et durée minimale d’une seconde par cycle).

Les principaux avantages sont un dépôt potentiellement plus précis grâce au bras, une meilleure répétabilité par repositionnement de la tête, et une architecture de locomotion simple (deux roues + roue-bille). Les principaux risques concernent la stabilité lors du déploiement du bras et la sensibilité au centre de masse; le bras doit donc rester court et léger, avec la batterie placée bas dans le châssis. Le concept respecte les contraintes d’autonomie (aucune télécommande), d’alimentation (piles 18650, maximum deux) et de masse totale (≤ 1,5 kg), mais des essais sur piste sont nécessaires pour valider la robustesse du dépôt et la reproductibilité des séquences.

22

Figures 2.4.1 – Croquis détaillés du concept 1


Note : Tous les croquis ci-dessus ont été réalisé initialement à la main. Par la suite, un logiciel de générations d’images a été utilisé pour parfaire les croquis. Le modèle utilisé est Gemini (Google)

Deuxième concept

Le second concept proposé est un chien-robot autonome à gabarit compact (≈30 cm de long et ≈20 cm de haut) conçu pour saisir le jouet « poulet », le transporter, puis le déposer dans la zone cible, tout en conservant une apparence explicite de chien et une locomotion sur roues. L’architecture regroupe un châssis porteur intégrant l’alimentation, l’électronique de commande (Arduino) et la structure, une tête avec mécanisme de mâchoire, un collier lumineux à LED rouges visible sur le pourtour du cou, un sous-ensemble moteur–transmission, des roues intégrées au niveau des pattes, ainsi qu’une queue motorisée. L’ensemble est démontable par vis afin de faciliter l’accès au compartiment moteur et la maintenance.

23

La manipulation est assurée par une mâchoire dont seule la partie inférieure s’ouvre vers le bas, ce qui libère le jouet par gravité au-dessus de la zone de dépôt. En position fermée, l’objet est retenu par deux dents type canines afin d’améliorer le maintien pendant le déplacement. La locomotion repose sur huit roues disposées par paires au niveau de chaque patte, avec une propulsion assurée par deux roues motrices en diagonale (avant gauche et arrière droite) afin d’améliorer la capacité de rotation. La transmission moteur–roues est réalisée par un système chaîne–roue dentée jouant un rôle de réduction pour augmenter le couple disponible. La signalisation est assurée par le collier LED rouge, tandis que la queue est entraînée par un moteur dédié produisant un battement périodique (≈1 à 2 s par cycle).

La séquence visée est la suivante : départ avec le jouet maintenu en gueule, déplacement jusqu’à la zone de dépôt, unique tentative de dépôt par ouverture de la mâchoire inférieure, puis exécution des actions demandées (collier LED et battement de queue) aux emplacements requis après orientation selon l’axe prescrit.

Les principaux avantages sont un dépôt simple et robuste (gravité, peu de pièces mobiles), un bon maintien du jouet, une manœuvrabilité améliorée par la motricité en diagonale, et un couple augmenté grâce à la réduction par chaîne. Les principaux risques sont une complexité mécanique plus élevée (8 roues et chaîne), une sensibilité à l’adhérence et au contrôle, un besoin de réglage/alignement de la chaîne, et une précision de dépôt dépendante de l’arrêt et de l’alignement au-dessus de la zone cible.

Figure 2.4.2 – Croquis détaillé du concept 2


24

Troisième concept

Le dernier concept retenu parmi les sept concepts évalués à l’aide de la matrice de Pugh est le concept « Robot-Chien SSG » (SSG pour sausage), nommé ainsi en raison de sa silhouette basse et allongée, rappelant une « saucisse ». Ce concept se distingue par plusieurs solutions mécaniques atypiques, conçues pour accomplir l’ensemble des tâches prescrites par le mandat.

Cette section présente le fonctionnement global du Robot-Chien SSG, puis décrit plus en détail ses différents sous-mécanismes. La figure X illustre un schéma de principe du concept, tandis que le tableau Y répertorie les principales pièces qui le composent.

Figure 2.4.3 – Croquis du concept 3


Tableau 2.4.1 – Description des pièces du concept 3

# | Description | Nombre

1 | Pattes décoratives | 4
2 | Ensemble queue battante | 1
3 | Système de propulsion et direction roue chenille | 1

25

Le fonctionnement global du robot reste simple. Pour se déplacer vers l’avant, vers l’arrière et pour modifier l’orientation de son axe longitudinal, il s’appuie sur un système roue-chenille, ce qui lui permet d’avancer et de pivoter de façon stable. Afin de conserver une apparence clairement associée à un chien, le concept intègre des pattes et des oreilles décoratives, ainsi qu’une silhouette basse et allongée rappelant un « chien saucisse ».

Un collier muni d’une DEL clignotante est placé autour de la zone du cou et des épaules pour assurer la signalisation visuelle. La mise en marche se fait à l’aide d’un bouton situé à l’arrière du robot. Un mécanisme de queue battante est également intégré afin d’ajouter un stimulus visuel. Enfin, l’accès aux composants internes est facilité par un couvercle amovible, ce qui simplifie l’inspection et la maintenance.

Système de propulsion et direction

Pour se déplacer, le Chien-Robot SSG utilise un système de roues entraînant des courroies en caoutchouc (type roue-chenille). De chaque côté, un moteur électrique fournit le couple à une roue motrice, qui entraîne la courroie; l’adhérence courroie–sol permet ensuite de faire avancer ou reculer le robot. Pour s’orienter, les deux courroies tournent en sens opposés, ce qui provoque une rotation du robot autour de son axe vertical (azimutal). La tension de chaque courroie est réglée à l’aide d’une roue de tension montée sur un support coulissant, ajustable via une plaque rainurée. Les croquis du système sont présentés à la figure 2.4.4.

4 | Oreilles décoratives | 2
5 | Système gueule-mâchoire actionné | 1
6 | Couvercle amovible | 1
7 | Bouton démarreur | 1
8 | Collier-Médaille DEL | 1
9 | Coque décorative et protective | 1

26

Figure 2.4.4 – Description du mécanisme du concept 3


Avantages : Grand control du déplacement et de la rotation du robot, Excellente stabilité.

Désavantages : Consommation énergétique (Hoekstra, 2025), Basse vitesse de déplacement (Hoekstra, 2025), Plus de pièces en mouvement

Système de queue battante

Le battement de la queue est assuré par un mécanisme de type bielle-manivelle. Un moteur électrique entraîne une manivelle qui lui est directement accouplée. Par l’intermédiaire d’une bielle et de pivots, la rotation est convertie en un mouvement alternatif transmis à un point d’attache situé près de l’axe de rotation de la queue. Ce mouvement impose alors une oscillation de la queue autour de son pivot. Le système est illustré à la figure 2.4.5.

Avantages : Peu de contrôle du moteur est nécessaire : il suffit de le faire tourner, peu importe le sens, pour faire battre la queue.

Désavantages : Système plus complexe, plus de pièces en mouvement

27

Figure 2.4.5 – Description du fonctionnement de la queue du concept 3


Système gueule-mâchoire actionnée

Pour maintenir le jouet « poulet » dans sa gueule puis le relâcher, le Chien-Robot utilise une mâchoire inférieure qui s’ouvre vers le bas. Afin d’assurer un bon maintien, cette mâchoire est équipée d’un ressort de torsion au niveau de son pivot, ce qui applique une force de serrage sur le jouet. Pour ouvrir la gueule, une bobine de fil entraînée par un moteur électrique tire sur la mâchoire à un point décalé de son axe de rotation. Le fonctionnement est illustré à la figure 2.4.6 ci-dessous.

Avantages : La gueule pour s’ouvrir et se refermer, mécanisme simple

Désavantages : Difficulté de dissimulé le fil (Hoekstra, 2025)

Figure 2.4.6 – Description du fonctionnement de la gueule du concept 3


28

Conclusion

Au terme des trois premières semaines du projet, les exigences du client ont été clarifiées et traduites en un cahier des charges structuré en fonctions principales, fonctions complémentaires et contraintes. Sur cette base, la génération d’idées et la matrice morphologique ont permis de proposer plusieurs solutions, qui ont ensuite été regroupées en six concepts préliminaires. Une première sélection a été réalisée à l’aide de la matrice de Pugh, ce qui a permis d’identifier trois concepts à fort potentiel pour la suite du développement.

La prochaine étape consistera à comparer ces trois concepts à l’aide d’une matrice de décision plus détaillée, afin de converger vers une solution finale qui se démarque de façon claire et justifiable. Cette comparaison s’appuiera sur des critères concrets et mesurables, accompagnés de justifications techniques. La masse et le nombre de pièces feront partie des critères obligatoires, puisqu’ils influencent directement la faisabilité, l’assemblage, la robustesse et le respect des contraintes du projet. À l’issue de cette démarche, un concept final sera retenu et servira de base aux étapes de conception détaillée, de fabrication et de validation du prototype.

29

Bibliographie

Hoekstra, L. (2025, JANVIER 30). Chenilles vs. roues motrices : Quelle est la meilleure option pour vous ? Récupéré sur BAS WORLD: https://www.basworld.com/fr/content/chenilles-vs-roues-motricesquelle-est-la-meilleure-option-pour-vous

30

ANNEXE

ANNEXE A – Détails sur le cahier de charge

No. | RÉV. | FONCTION | K | CRITÈRE | NIVEAU | FLEXIBILITÉ | COMMENTAIRES
FP | | Fonctions principales
FP-1.0 | 2 | Se déplacer | 5 | Bouger sur à travers la piste sans franchir la zone limite | Dimensions de la piste | Aucune | Évaluation de la facilité avec laquelle le robot peut se déplacer
FP-1.1 | 2 | S'immobiliser | 5 | Arriver à une vitesse 0 | Vitesse de freinage | Aucune | Évaluation de la décélération
FP-2.0 | 2 | Tourner sur lui-même | 5 | Tourner dans les cercles rouges de la piste | Cercle de rayon 25 cm | +0 cm / minimum ouvert | Facilité qu'a le robot à tourner sur lui-même dans un cercle de rayon donné
FP-3.0 | 2 | Allumer un voyant lumineux | 4 | Le voyant clairement visible | Luminosité en candelas: 300 mcd | Minimum 300 mcd | Le voyant luminant doit être visible de tous les cotés
FP-3.1 | 2 | S'allumer en intervalle défini | 4 | Voyant lumineux s'allume en intervalle de 1 seconde | Intervalle: 1 sec | +1/0 sec
FP-3.2 | 2 | Être visible à distance | 3 | Le voyant est facilement visible à une distance de 1.5 m | Distance: 1.5 m | Ouverte

FP-

4.0 | 2 | Manipuler la charge
utile | 3

Déposer l'objet dans
un espace défini

Précision
du largage Aucune

L'objet doit être déposer dans la zone avec une précision plus grande ou égale à celle de la zone cible

FP-4.1 | 2 | Transporter un objet | 3 | Peut transporter un objet de forme cylindrique | 32 mm DIA et 130 mm LONG | +/- 10 mm par dimension
FP-4.2 | 2 | Maintenir l'objet | 3 | Peut maintenir l'objet dans sa gueule | Masse:30g minimum | Aucune
FP-4.3 2 | | Déposer un objet dans une zone prédéterminé | 3 | Déposer l'objet dans un espace défini | Cercle de rayon 5 cm | + 0/- 0.5 m
FP-5.0 | 2 | Battre de la queue | 4 | La queue bouge de gauche à droite de façon périodique | Cycle de 1 seconde (min 3 cycle) | Minimum 1 sec par cycle
FP-5.1 2 | | Contrôler la cadence du battement | 4 | Durée du cycle de battement | 1 seconde | ≥ 1s
FP-5.2 2 | | Maintenir l'amplitude de battement | 3 | Angle par rapport à la verticale | 45 degrés | ≥ 45 degrés
FP-6.0 | 2 | Démarrer via bouton/interrupteur | 4 | Bouton/interrupteur sur le robot-chien | Accès au bouton | Aucune | Le bouton doit être clairement accessible sur le robot

No. | RÉV. | FONCTION | K | CRITÈRE | NIVEAU | FLEXIBILITÉ | COMMENTAIRES
FC | Fonctions complémentaires
FC-1.0 | 0 | Maximiser la masse du produit mobile | 4 | Masse du produit | 1.5 kg | +/- 0.5 kg | Il faut imposer une limite supérieure afin de ne pas trop ralentir le produit mobile
FC-2.0 | 0 | Minimiser la longueur du produit mobile | 4 | Longueur du produit mobile | 12.5 cm | +/- 2.5 cm
FC-3.0 | 1 | Minimiser l’encombrement du produit mobile | 3 | Volume occupé par le produit mobile | 1 125 cm³ | Maximum (+ 0, /- ouvert)
FC-4.0 | 2 | Minimiser le nombre de pièces différentes utilisées dans le produit mobile | 2 | Nombre de pièces différentes utilisées dans le produit mobile | 20 Maximum (+ | 0, /- ouvert) | Ces deux fonctions sont en rapport avec la simplicité désirée du produit
FC-5.0 | 2 | Minimiser le nombre de pièces totales utilisées dans le produit mobile | 2 | Nombre de pièces totales utilisées dans le produit mobile | 40 Maximum (+ | 0, /- ouvert)
FC-1.0 | 1 | Compléter le parcours bonus | 1 | Compléter les tâches du parcours bonus | Temps de complétion <30sec | Aucune | Dans le cas où le robot est permis de faire le parcours bonus
FC-1.1 | 1 | Respecter l'intervalle de temps alloué | 1 | Intervalle de temps en seconde | 30s | 30s + 30s (au besoin)
FC-1.2 | 1 | Se réaligner vers X | 1 | Axe longitudinal du chien aligner vers le X | Diamètre du cercle autour du X | Aucune

FC-2.0 | 1 | Être facilement
réparable | 2

Pouvoir
réparer les
pièces
2h | ±20min | Durée estimée si des pièces de
rechanges sont à disposition
FC-2.1 | 1 | Accessibilité des pièces | 2 | Accès facile au compartiment utile | Pourcentage du système accessible en cas de panne -80% | +20%
FC-2.2 | 1 | Coût des réparations | 2 | Prix moyen de chaque réparation | 20-30$ | ±10$
FC-2.3 | 1 | Aisance de la réparation | 2 | Simplicité et indépendance des systèmes | | | Les systèmes sont facilement séparables les uns des autres
FC-3.0 | 1 | Maximiser l'efficience énergétique | 1 | Nombre de piles utilisées | Maximum 2 pile | Aucune
FC-4.0 | 1 | Être esthétique | 3 | Nombre de fils apparents qui sont « flottants » ou non fixés | 0 | Aucune | Les fils électriques doivent être ou entièrement dissimulés,
FC-4.1 | 1 | Ressembler à un chien | 3 | Avoir une tête et une queue | Morphologie | Aucune | Le robot devra ressembler à la morphologie d'un chien
FC-5.0 | 1 | Être de construction recyclable | 3 | Nombre d'utilisations avant besoin d'entretien ou réparation | 200 | ± 10 | Estimé
FC-6.0 | 1 | Être facilement rechargeable | 2 | Port de charge sur le chien-robot | Facilité d'accès des batteries ou du port de charge | Aucune
FC-7.0 | 1 | Être original | 2 | Unique dans sa conception et morphologie | N/A | N/A | Le robot est démarqué des autres

Optimiser le; budget; Simplicité de la conception et matériaux non dispendieux; Économie; Le robot respect le budget avec une marge d'environ 20%; Stabilité du robot; Hauteur du centre de masse du robot; haut; Plus le centre de masse est bas, plus le robot est stable

No. | RÉV. | FONCTION | K | CRITÈRE | NIVEAU | FLEXIBILITÉ | COMMENTAIRES
CO | Fonctions contraintes
CO-1.0 | 1 | Être léger | 4 | maximum : 1,5 kg | 3 | Maximum (+ 0, /- ouvert)
CO-2.0 1 | | Être complètement autonome | 5 | Aucune intervention humaine | Aucune | Aucune
CO-3.0 | 1 | Respecter le budget | 3 | Maximum: 400$ | 400$ | Aucune
CO-4.0 1 | | Completer le parcours obligatoire dans l'intervalle de temps alloué | 4 | Maximum: 120 s | 1 | Maximum (+ 0, /- ouvert)
CO-5.0 | 1 | Être sécuritaire | 5 | Nombre d'arêtes tranchantes | 0 | Aucune
| | | | Nombre de projectiles pouvant être projetés par le produit en opération | 0 Aucune | | Le produit doit être sécuritaire pour toute personne le manipulant ou se situant proche de lui
CO-6.0 | 1 | Être compact | 5 | Rentrer dans une cube de 30 cm x 30 cm x 45 cm | 2 Maximum (+ | 0, /- ouvert)
CO-7.0 1 | | Respecter le nombre maximal de batterie rechargeable | 5 | 2 batteries 18650 de 3200 mAh et de 3,6-3,7 V | 1 Maximum (+ | 0, /- ouvert)
CO-8.0 1 | | Fiabilité du programme informatique | 4 | Fonctionnement du code en fonction du nombre d'utilisation | 80% | (-10% ou +20%) | Le code devra fonctionner au moins 80% du temps

ANNEXE B – Détails sur le C.R.A.P.E.AU (concept 1)


Le C.R.A.P.E.A.U. est un chien-robot quadrupède monté sur roues. Il possède huit roues, disposées par paires au niveau de chaque patte. Les roues motrices sont placées en diagonale (patte avant gauche et patte arrière droite). Le mouvement est transmis des moteurs aux roues à l’aide d’un système chaîne–roue dentée jouant le rôle de réducteur, ce qui augmente le couple disponible.

Le collier est constitué d’une chaîne d’ampoules LED rouges placées au niveau du cou, offrant une visibilité à 360°. La mâchoire est rotative de façon à ce que seule la partie inférieure simule une mandibule de chien, ce qui permet de laisser tomber les objets. En position fermée, l’objet est retenu par deux dents simulant des canines. La queue est montée sur l’arbre d’un moteur, ce qui lui permet de battre en cycles d’environ 1 à 2 secondes. Enfin, le robot est conçu pour être démontable facilement à l’aide de vis, afin de faciliter l’ouverture du compartiment moteur.

Note : Correction de l’orthographe avec l’IA

ANNEXE C – Détails sur le CHIHUAHUA (Concept 2)


ANNEXE D – Détails sur les pointages pondérés et bruts de la matrice de Pugh

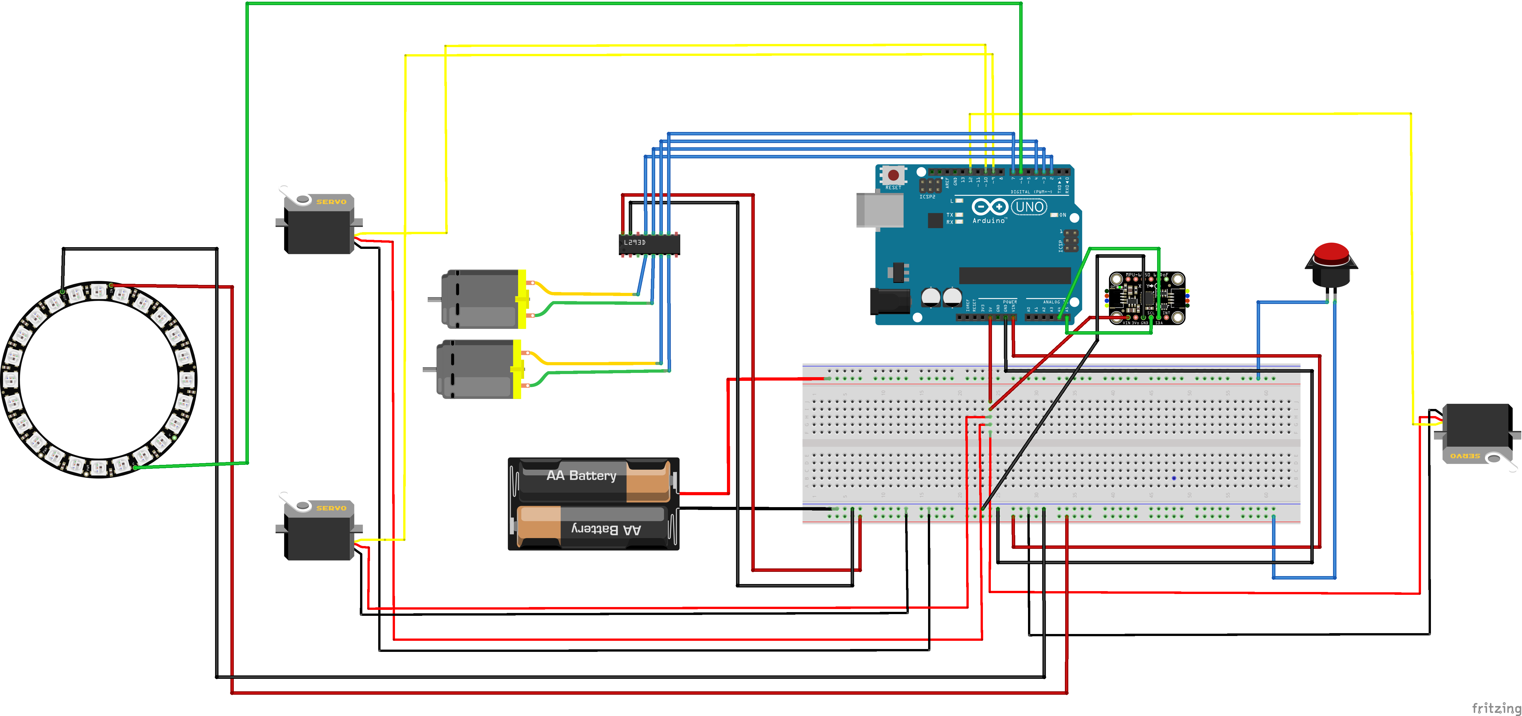
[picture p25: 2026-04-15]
Circuit/Circuit Éléctrique.png

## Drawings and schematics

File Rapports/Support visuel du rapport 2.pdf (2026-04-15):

Le 23 février 2026
Dans le cadre du cours Projet Intégrateur II - MEC2105, Groupe 02
Par Adam Bouaddi, Liliane Leclerc-Ko, Miguel El Azoury, Rose Melançon, Ryan Kangue et William Lalonde

# Plan de présentation ²

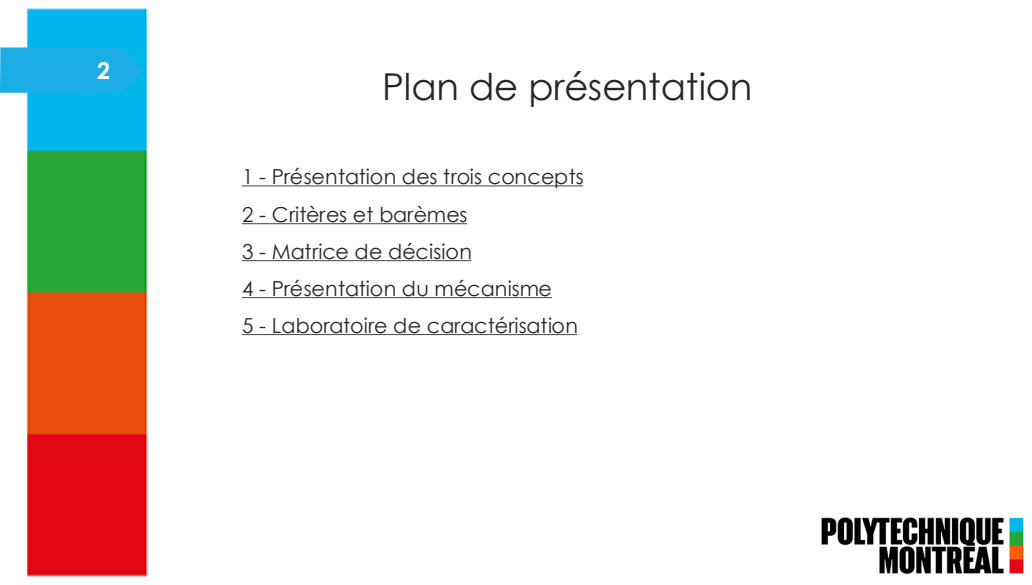
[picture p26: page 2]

1 - Présentation des trois concepts
2 - Critères et barèmes
3 - Matrice de décision
4 - Présentation du mécanisme
5 - Laboratoire de caractérisation

3

1 - Présentation des trois concepts

# 1.1 Crapeau ⁴

## 1. Présentation des trois

• Systeme à deux roues
motrices.

• Surélevé par rapport au sol.

• Roue motrice disposées en
diagonale.

# 5 1.1.1 Fonctionnement:

## caractérisation

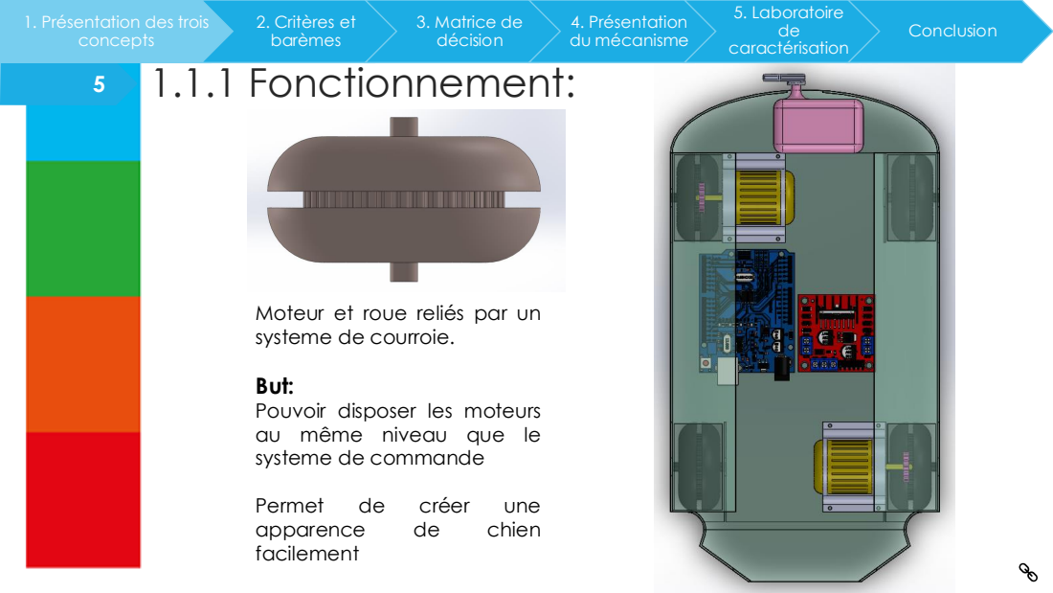
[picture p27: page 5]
Permet; créer; une; apparence; chien; facilement

Moteur et roue reliés par un
systeme de courroie.

But:
Pouvoir disposer les moteurs
au même niveau que le
systeme de commande

# Avantages:

# Désavantages:

1.1.2 Avantages et désavantages ⁶

• Centre de masse élevé,
risque de perte d'équilibre.

• Haute vitesse en ligne droite.

• Petite taille et masse reduite

• Complexité du système
moteur.

• Esthetique de chien
apparente.

• Diffiulté de délivrer la charge
avec précision.

# 1.2 Z-Neck ⁷

## caractérisation

• Système de bras articulé.

• Deux roues motrices.

# 8 1.2.1 Fonctionnement:

## caractérisation

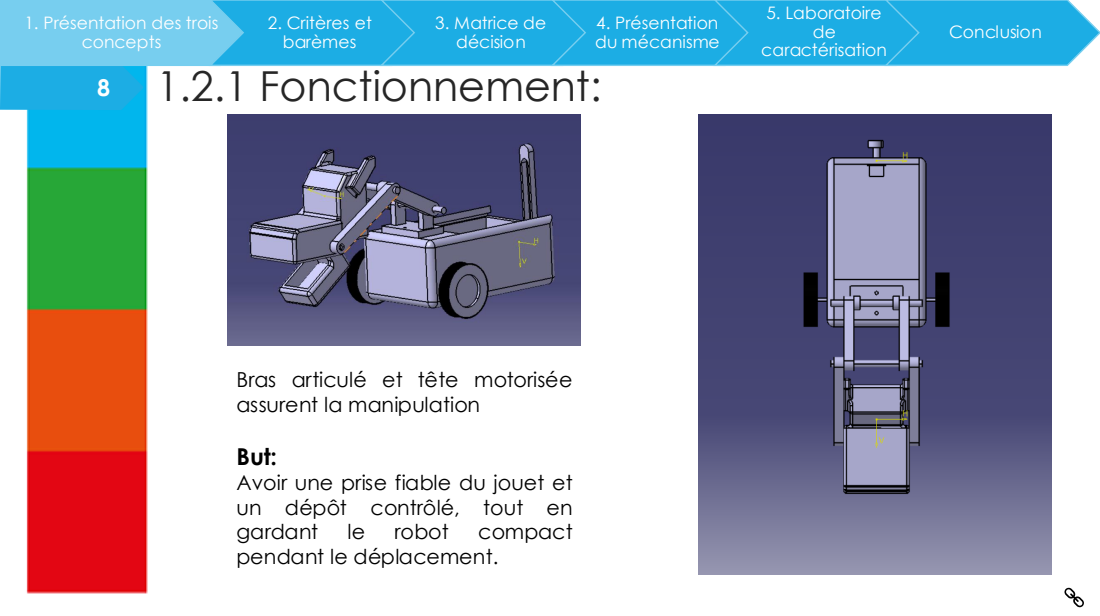
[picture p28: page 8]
gardant; robot; compact

Bras articulé et tête motorisée
assurent la manipulation

But:
Avoir une prise fiable du jouet et
un dépôt contrôlé, tout en
pendant le déplacement.

# Avantages:

# Désavantages:

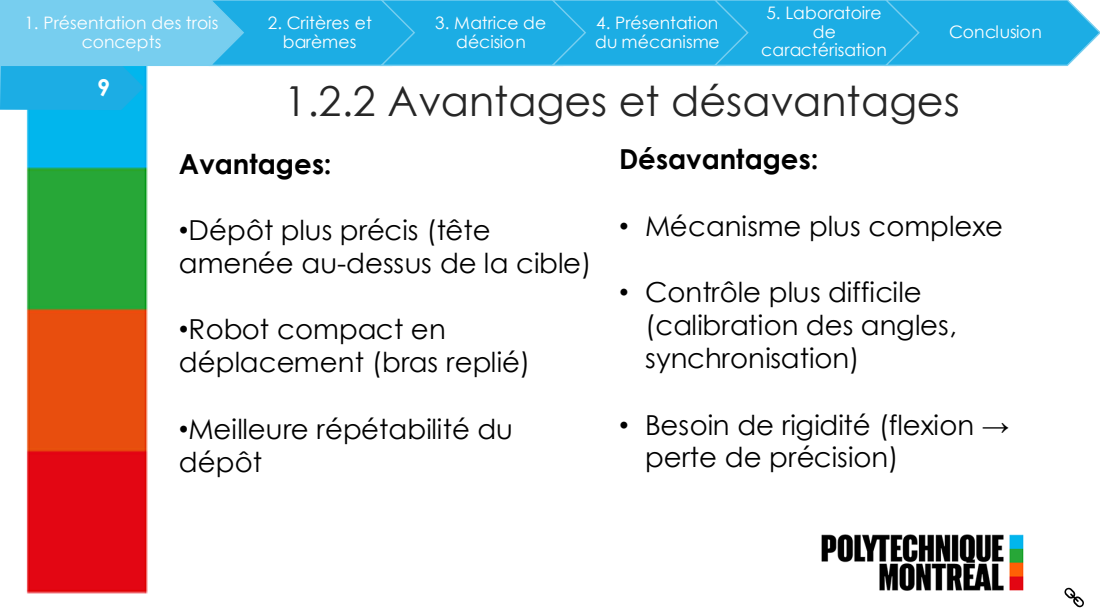
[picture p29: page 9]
caractérisation

1.2.2 Avantages et désavantages ⁹

• Mécanisme plus complexe

•Dépôt plus précis (tête
amenée au-dessus de la cible)

• Contrôle plus difficile
(calibration des angles,
synchronisation)

•Robot compact en
déplacement (bras replié)

• Besoin de rigidité (flexion →
perte de précision)

•Meilleure répétabilité du
dépôt

# 10 1.3 Chien-Robot SSG

## caractérisation

motorisées

• Centre de masse très bas

• Permet d'utiliser plusieurs
étages pour répartir les
composants

# 1.3.1 Fonctionnement ¹¹

## caractérisation

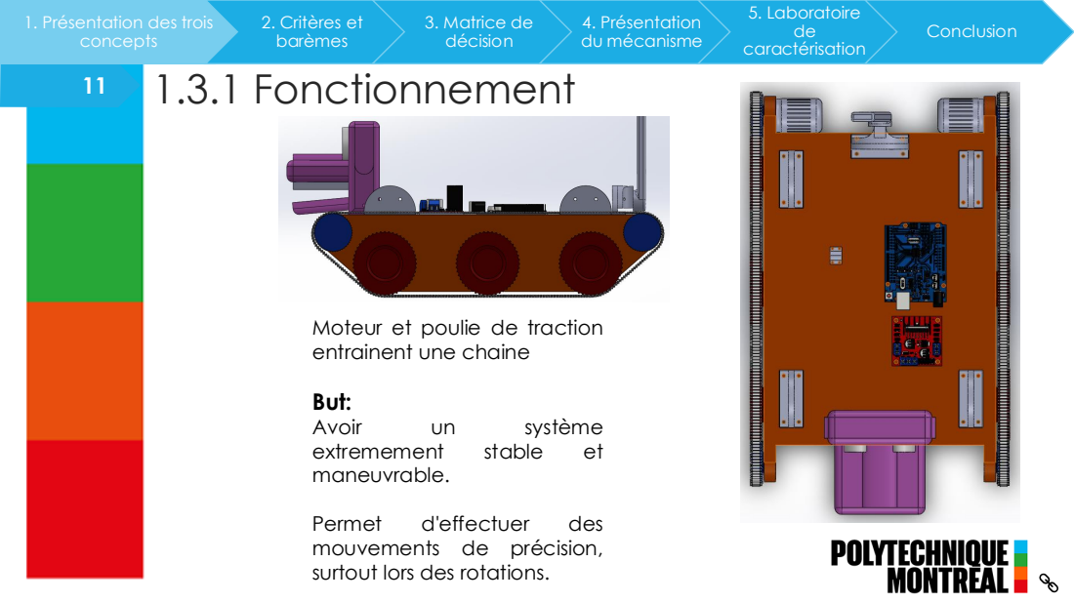
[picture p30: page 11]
But:; Avoir; système; extremement; stable; maneuvrable.; Permet; d'effectuer; des

Moteur et poulie de traction
entrainent une chaine

mouvements de précision,
surtout lors des rotations.

# Avantages:

# Désavantages:

1.3.2 Avantages et désavantages ¹²

• Stabilité lors des phases
d'accélération.

• Vitesse de croisière lente.

• Couteux au niveau de
l'énergie du fait de la masse.

• Facilité à effectuer des
rotations.

• Nombre élevé de pièce.

• Répartition equitable du
poids (Centre de gravité
centré).

13

## caractérisation

2 - Critères et barèmes

# 2.1 Tableau synthèse des critères

14

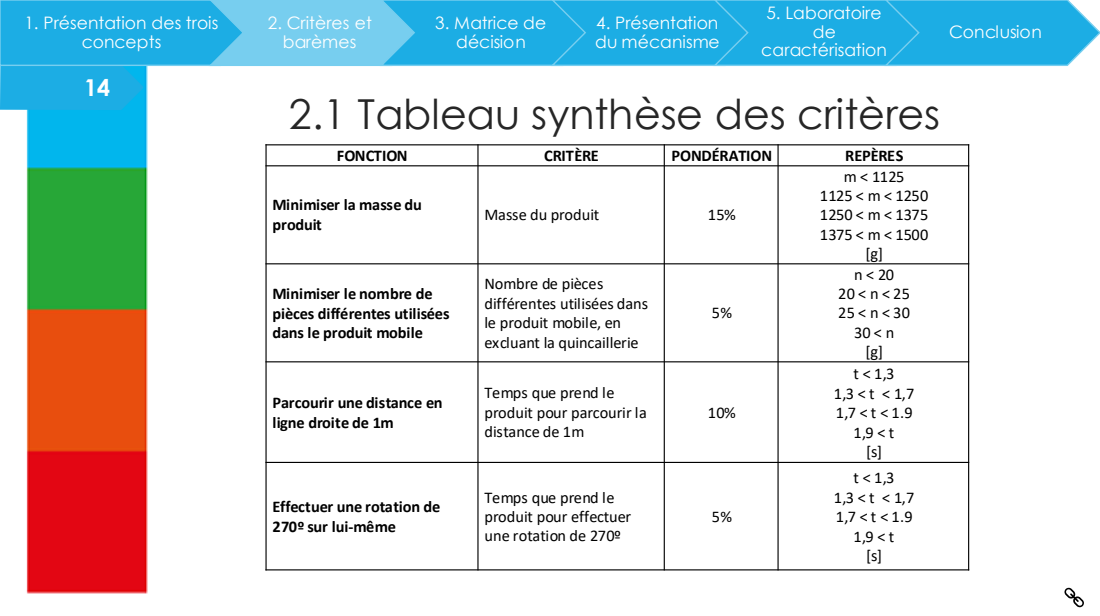
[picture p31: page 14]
caractérisation

FONCTION | CRITÈRE | PONDÉRATION | REPÈRES

Minimiser la masse du produit | Masse du produit | 15% | m < 1125 1125 < m < 1250 1250 < m < 1375 1375 < m < 1500 [g]

Minimiser le nombre de pièces différentes utilisées dans le produit mobile | Nombre de pièces différentes utilisées dans le produit mobile, en excluant la quincaillerie | 5% | 20 < n < 25 25 < n < 30 30 < n [g]

Parcourir une distance en ligne droite de 1m | Temps que prend le produit pour parcourir la distance de 1m | 10% | 1,3 < t < 1,7 1,7 < t < 1.9 1,9 < t [s]

Effectuer une rotation de 270º sur lui-même | Temps que prend le produit pour effectuer une rotation de 270º | 5% | t < 1,3 1,3 < t < 1,7 1,7 < t < 1.9 1,9 < t [s]

# 15 2.1 Tableau synthèse des critères (suite)

Effectuer une rotation avec précision | Rayon de rotation | 15% | r < 4 4 < r < 8 8< r < 12 12 < r [cm]

Avoir un voyant lumineux visible tout autour du chien à | Le voyant est clairement visible tout autour du chien | 10% | 270 < θ < 360 180 < θ < 270 90 < θ < 180

1,5m peu importe la direction | | 0 < θ < 90

[degrés]

Précision du dépôt de la charge utile | Hauteur de largage du jouet poulet | 10% | 0 < h < 5 5 < h < 10 10 < h < 15

15 < h < 20
[cm]

Maximiser l'efficacité énergetique | Quantité d'énergie utilisé par le robot | 15% | E< 100 100 < E <120 120< E < 140 140<E [joules]

Stabilité du robot | Hauteur du centre de gravité | 15% | h < 8 8 < h < 10 10 < h < 12 12 < h [cm]

17

## caractérisation

3 – Matrice de décision

# 18 3.1 Tableau synthèse de la matrice de décision

## caractérisation

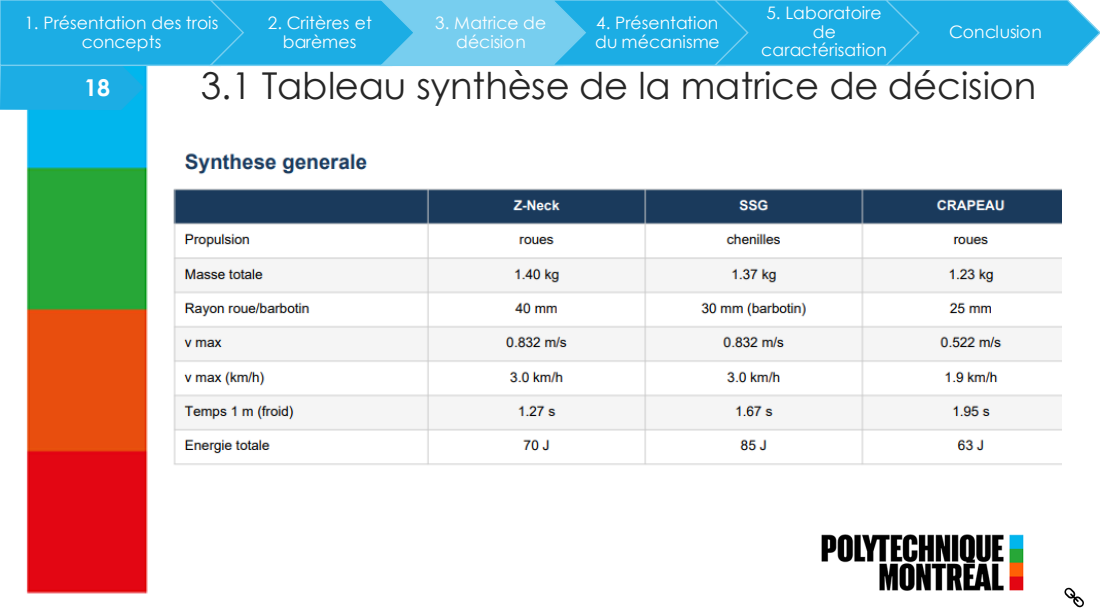
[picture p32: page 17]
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

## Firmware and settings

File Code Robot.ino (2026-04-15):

// ============================================================
//  LE DALMACHIEN - V3 PARCOURS AVEC GYROSCOPE MPU6050
//  Équipe 24 - MEC2105 - Polytechnique Montréal - H2026
// ============================================================

#include <Servo.h>
#include <Adafruit_NeoPixel.h>
#include <Wire.h>

// ============================================================
//  VARIABLES À CALIBRER
// ============================================================
const float VITESSE_MS = 7000;  // ms par mètre (1 m en 3.5 s) *** CALIBRER ***
const float GYRO_TOLERANCE = 2.0;    // degrés
const float DEG_PAR_SEC = 112.0;     // pour timeout sécurité

// Distances parcours (cm)
const float DIST_1  = VITESSE_MS*0.70;   // montée initiale
const float DIST_3  = VITESSE_MS*0.15;   // avance vers poulet
const float DIST_5  = VITESSE_MS*0.20;   // recul après poulet
const float DIST_9  = VITESSE_MS*1.30;   // traversée
const float DIST_12 = VITESSE_MS*0.65;   // avance finale

// Queue
const int QUEUE_CENTRE      = 90;
const int QUEUE_AMPLITUDE   = 150;
const int QUEUE_DUREE_CYCLE = 1500;
const int QUEUE_NB_CYCLES   = 3;

// LED
const uint8_t LED_R = 0, LED_G = 255, LED_B = 0;
const int LED_ON_MS  = 500;
const int LED_OFF_MS = 1000;
const int LED_NB_CLIGNO = 3;

// ============================================================
//  PINS
// ============================================================
const int IN1 = 2, IN2 = 3, IN3 = 4, IN4 = 7;
const int PIN_QUEUE = 12;
const int PIN_TETE_G = 9;
const int PIN_TETE_D = 10;
const int PIN_LED   = 6;
const int NB_LEDS   = 20;
const int MPU_ADDR  = 0x68;

// Tete
const int TETE_VERTICAL   = 98;
const int TETE_HORIZONTAL = 20;
const int TETE_MS_PAR_DEG = 15;
const int ACOUP_HAUT   = 30;
const int ACOUP_BAS    = 10;
const int ACOUP_VITESSE = 10;  // ms par degre
const int ACOUP_PAUSE  = 50;   // ms entre a-coups
const int ACOUP_NB     = 5;

// ============================================================
//  OBJETS
// ============================================================
Servo servoQueue, servoTeteG, servoTeteD;
Adafruit_NeoPixel strip(NB_LEDS, PIN_LED, NEO_GRB + NEO_KHZ800);
int angleTete = TETE_VERTICAL;
float angleZ = 0.0;
unsigned long lastGyroTime;

// ============================================================
//  MPU6050
// ============================================================
void initMPU() {
  Wire.begin();
  Wire.beginTransmission(MPU_ADDR);
  Wire.write(0x6B); Wire.write(0);
  Wire.endTransmission(true);
  Wire.beginTransmission(MPU_ADDR);
  Wire.write(0x1B); Wire.write(0x00); // ±250°/s
  Wire.endTransmission(true);
  delay(100);
  angleZ = 0.0;
  lastGyroTime = millis();
}

float readGyroZ() {
  Wire.beginTransmission(MPU_ADDR);
  Wire.write(0x47);
  Wire.endTransmission(false);
  Wire.requestFrom(MPU_ADDR, 2, true);
  int16_t raw = (Wire.read() << 8) | Wire.read();
  return raw / 131.0;
}

void updateAngle() {
  unsigned long now = millis();
  float dt = (now - lastGyroTime) / 1000.0;
  lastGyroTime = now;
  angleZ += readGyroZ() * dt;
}

void resetAngle() {
  angleZ = 0.0;
  lastGyroTime = millis();
}

// ============================================================
//  MOTEURS
// ============================================================
void avancer()       { digitalWrite(IN1,HIGH); digitalWrite(IN2,LOW);  digitalWrite(IN3,HIGH); digitalWrite(IN4,LOW);  }
void reculer()       { digitalWrite(IN1,LOW);  digitalWrite(IN2,HIGH); digitalWrite(IN3,LOW);  digitalWrite(IN4,HIGH); }
void tournerDroite() { digitalWrite(IN1,LOW);  digitalWrite(IN2,HIGH); digitalWrite(IN3,HIGH); digitalWrite(IN4,LOW);  }
void tournerGauche() { digitalWrite(IN1,HIGH); digitalWrite(IN2,LOW);  digitalWrite(IN3,LOW);  digitalWrite(IN4,HIGH); }
void stopMotors()    { digitalWrite(IN1,LOW);  digitalWrite(IN2,LOW);  digitalWrite(IN3,LOW);  digitalWrite(IN4,LOW);  }

void go(float ms) {
  if (ms <= 0) return;
  avancer(); delay((int)ms); stopMotors();
}

void back(float ms) {
  if (ms <= 0) return;
  reculer(); delay((int)ms); stopMotors();
}

void rotGyro(bool droite, float degres) {
  if (degres <= 0) return;
  resetAngle();
  unsigned long timeout = (unsigned long)(degres / DEG_PAR_SEC * 1000) * 3;
  droite ? tournerDroite() : tournerGauche();
  unsigned long start = millis();
  while (true) {
    updateAngle();
    if (abs(angleZ) >= degres - GYRO_TOLERANCE) break;
    if (millis() - start > timeout) { Serial.println(F("TIMEOUT!")); break; }
    delay(2);
  }
  stopMotors();
  delay(200);
}

// ============================================================
//  QUEUE
// ============================================================
void mouvQueue(int de, int a, int ms) {
  de = constrain(de,0,180); a = constrain(a,0,180);
  int n = abs(a-de); if (!n) return;
  int d = max(ms/n,1); int step = (de<a)?1:-1;
  for (int p=de; p!=a+step; p+=step) { servoQueue.write(p); delay(d); }
}

void batQueue() {
  int g = constrain(QUEUE_CENTRE - QUEUE_AMPLITUDE/2, 0, 180);
  int d = constrain(QUEUE_CENTRE + QUEUE_AMPLITUDE/2, 0, 180);
  servoQueue.write(QUEUE_CENTRE); delay(200);
  for (int i=0; i<QUEUE_NB_CYCLES; i++) {
    mouvQueue(QUEUE_CENTRE, g, QUEUE_DUREE_CYCLE/4);
    mouvQueue(g, d, QUEUE_DUREE_CYCLE/2);
    mouvQueue(d, QUEUE_CENTRE, QUEUE_DUREE_CYCLE/4);
  }
  servoQueue.write(QUEUE_CENTRE);
}

// ============================================================
//  TETE
// ============================================================
void ecrireTete(int angle) {
  servoTeteG.write(angle);
  servoTeteD.write(180 - angle);
}

void bougerTete(int cible) {
  if (cible == angleTete) return;
  int step = (cible > angleTete) ? 1 : -1;
  for (int a = angleTete; a != cible; a += step) {
    ecrireTete(a);
    delay(TETE_MS_PAR_DEG);
  }
  ecrireTete(cible);
  angleTete = cible;
}

void aCoupsTete() {
  for (int i = 0; i < ACOUP_NB; i++) {
    int step = (ACOUP_HAUT > ACOUP_BAS) ? 1 : -1;
    for (int a = ACOUP_BAS; a != ACOUP_HAUT; a += step) {
      ecrireTete(a); delay(ACOUP_VITESSE);
    }
    ecrireTete(ACOUP_HAUT);
    delay(ACOUP_PAUSE);
    for (int a = ACOUP_HAUT; a != ACOUP_BAS; a -= step) {
      ecrireTete(a); delay(ACOUP_VITESSE);
    }
    ecrireTete(ACOUP_BAS);
    delay(ACOUP_PAUSE);
  }
  angleTete = ACOUP_BAS;
}

void sequenceDepot() {
  Serial.println(F("  Tete: descente"));
  bougerTete(TETE_HORIZONTAL);
  delay(2000);
  //Serial.println(F("  Tete: a-coups"));
  //aCoupsTete();
  //delay(1000);
  Serial.println(F("  Tete: remontee"));
  bougerTete(TETE_VERTICAL);
}

// ============================================================
//  LED
// ============================================================
void ledOn()  { for(int i=0;i<NB_LEDS;i++) strip.setPixelColor(i,strip.Color(LED_R,LED_G,LED_B)); strip.show(); }
void ledOff() { strip.clear(); strip.show(); }
void ledBlink(int n) { for(int i=0;i<n;i++){ ledOn(); delay(LED_ON_MS); ledOff(); delay(LED_OFF_MS); } }

// ============================================================
//  PARCOURS
// ============================================================
void setup() {
  Serial.begin(9600);
  pinMode(IN1,OUTPUT); pinMode(IN2,OUTPUT);
  pinMode(IN3,OUTPUT); pinMode(IN4,OUTPUT);
  stopMotors();

  servoQueue.attach(PIN_QUEUE);
  servoQueue.write(QUEUE_CENTRE);
  servoTeteG.attach(PIN_TETE_G);
  servoTeteD.attach(PIN_TETE_D);
  ecrireTete(TETE_VERTICAL);
  strip.begin(); strip.show(); ledOff();
  initMPU();

  Serial.println(F("=== DALMACHIEN V3 PRET ==="));
  delay(2000);

  // 1. Avancer 30 cm
  Serial.println(F("1: Avancer 30cm"));
  go(DIST_1);
  delay(300);

  // 2. Tourner 45° anti-horaire
  Serial.println(F("2: Rot 45 gauche"));
  rotGyro(false, 45);
  delay(300);

  // 3. Avancer 15 cm
  Serial.println(F("3: Avancer 15cm"));
  go(DIST_3);
  delay(300);

  // 4. Depot poulet (tete baisse + a-coups + remonte)
  Serial.println(F("4: Depot poulet"));
  sequenceDepot();

  // 5. Reculer 15 cm
  Serial.println(F("5: Reculer 15cm"));
  back(DIST_5);
  delay(300);

  // 6. Tourner 90° anti-horaire
  Serial.println(F("6: Rot 90 gauche"));
  rotGyro(false, 90);
  delay(300);

  // 7. LED clignote 3x
  Serial.println(F("7: LED x3"));
  ledBlink(LED_NB_CLIGNO);
  delay(300);

  // 9. Tourner 45° horaire
  Serial.println(F("9: Rot 45 droite"));
  rotGyro(true, 55);
  delay(300);

  // 10. Avancer 70 cm
  Serial.println(F("10: Avancer 70cm"));
  go(DIST_9);
  delay(300);

  // 11. Tourner 90° anti-horaire
  Serial.println(F("11: Rot 90 gauche"));
  rotGyro(false, 125);
  delay(300);

  Serial.println(F("13: Queue bat"));
  batQueue();
  delay(25000);

  // FIN DU PARCOURS OBLIGATOIRE

    // 8. Tourner 45° horaire
  Serial.println(F("8: Rot 45 droite"));
  rotGyro(true, 50);

  
  delay(300);

  // 12. Avancer 30 cm
  Serial.println(F("12: Avancer 30cm"));
  go(DIST_12);
  delay(300);


  // 14. Rotation 360° sur soi-même
  Serial.println(F("14: Rot 360"));
  rotGyro(true, 270);
  delay(300);

  // FIN
  stopMotors();
  servoQueue.write(QUEUE_CENTRE);
  ledOff();
  Serial.println(F("=== FIN PARCOURS ==="));
}

void loop() {}

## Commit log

2026-04-15 Add README for autonomous robot dog project
    Added detailed project information for the autonomous robot dog prototype, including mission objectives, hardware specifications, required libraries, pinout, calibration settings, and licensing.
2026-04-15 Ajout des rapports RP1, RP2, RP3 et code Arduino du robot
2026-04-15 Ajout du circuit électrique (Fritzing + PNG)
    [Circuit Éléctrique.fzz]
